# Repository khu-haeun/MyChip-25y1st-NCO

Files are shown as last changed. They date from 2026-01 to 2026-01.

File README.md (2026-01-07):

# My Chip Service 25y1st: **12-bit CORDIC-based NCO**

## Notice: What is **My Chip Service**?
An initiative in South Korea that provides MPW (Multi-Project Wafer) services using public fabrication facilities (fabs) for undergraduate and graduate students.
* **Official Website:** [https://www.moafab.kr](https://www.moafab.kr/css/myPage/bussiness/myChip/info)
* **Design Kit (Open-Source):** [ETRI 0.5um CMOS MPW Standard Cell DK](https://github.com/GoodKook/ETRI-0.5um-CMOS-MPW-Std-Cell-DK/tree/main)

---

## Project: 12-bit CORDIC-based NCO

### 1. Overview
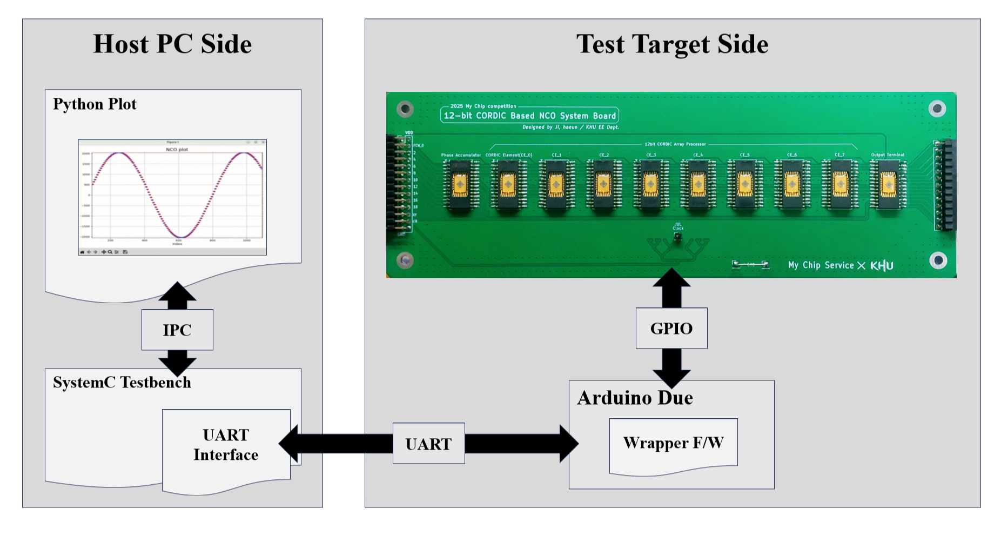
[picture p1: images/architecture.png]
Test architecture.

*Fig 1. System Architecture*

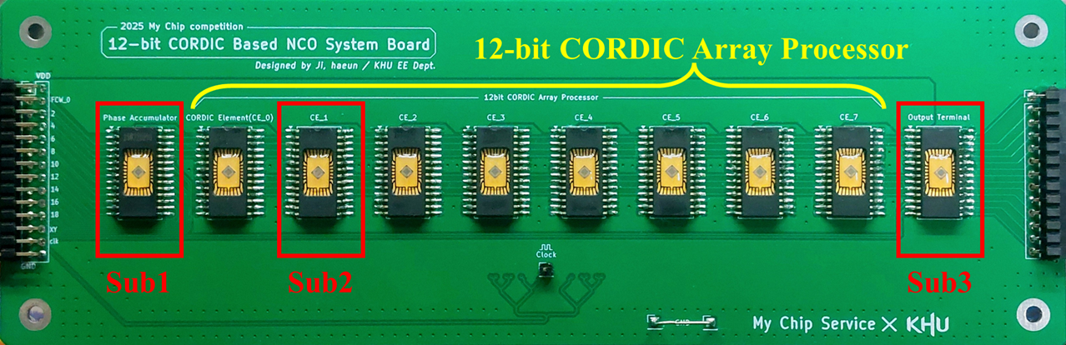
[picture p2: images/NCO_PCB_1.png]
NCO implemented on a PCB using 'My Chip'.

*Fig 2. NCO implemented on a PCB using 'My Chip'*

* **Description:** A **Numerically Controlled Oscillator (NCO)** is a digital circuit that generates synchronous, discrete-time, discrete-valued representations of sinusoidal waveforms. This project implements an NCO using a **CORDIC (Coordinate Rotation Digital Computer)** array processor to calculate trigonometric values. The complete verification environment and system structure are illustrated in **Fig 1**.

* **Key Challenges: Overcoming Physical Constraints**
    * **Core Limits:** Since the NCO design exceeded the single-chip area limit, it was **partitioned into three sub-circuits** as shown in **Fig 2**:
        1. **Phase Accumulator:** Generates the phase angle.
        2. **CORDIC Processing Element:** Performs the vector rotation.
        3. **Output Terminal:** Manages the final data output, including quadrant restoration.
    * **Pad Limits:** Each chip is limited to **28 pins**. the I/O for each sub-circuit was implemented using a **2-bit serial interface**.

---

### 2. Directory Structure
```text
├── 0_Algorithm (Algorithm development, including output plots and verification)
│   ├── c_untimed: C-based NCO algorithm
│   ├── cpp_untimed: C++ based NCO algorithm
│   └── sc_timed: SystemC-based NCO model (Clock-event-based cycle-accurate design)
|
├── 1_Parallel_IO (Reference design using parallel I/O (Not implemented in this version))
|
├── 2_Splited_IO (RTL-to-GDS with Open-Source Design Kit, including output plots and verification)
│   ├── 2_0_Top_NCO: Integrated NCO system comprising all three sub-circuits
│   ├── 2_1_Phase_Acc: Sub-circuit 1
│   ├── 2_2_Cordic_Element: Sub-circuit 2
│   ├── 2_3_Output_Terminal: Sub-circuit 3
|
└── 3_Application (application cases)
    ├── 3_0_Generate_Sinusoid: Sinusoidal waveform generation
    ├── 3_1_QPSK_Communication_prototype: QPSK simulation for the prototype board
    └── 3_2_QPSK_Communication_pcb: QPSK simulation for the final PCB

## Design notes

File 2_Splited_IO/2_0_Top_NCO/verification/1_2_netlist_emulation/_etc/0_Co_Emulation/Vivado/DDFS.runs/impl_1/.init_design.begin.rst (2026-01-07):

<?xml version="1.0"?>
<ProcessHandle Version="1" Minor="0">
    <Process Command=".planAhead." Owner="ji" Host="" Pid="7366">
    </Process>
</ProcessHandle>

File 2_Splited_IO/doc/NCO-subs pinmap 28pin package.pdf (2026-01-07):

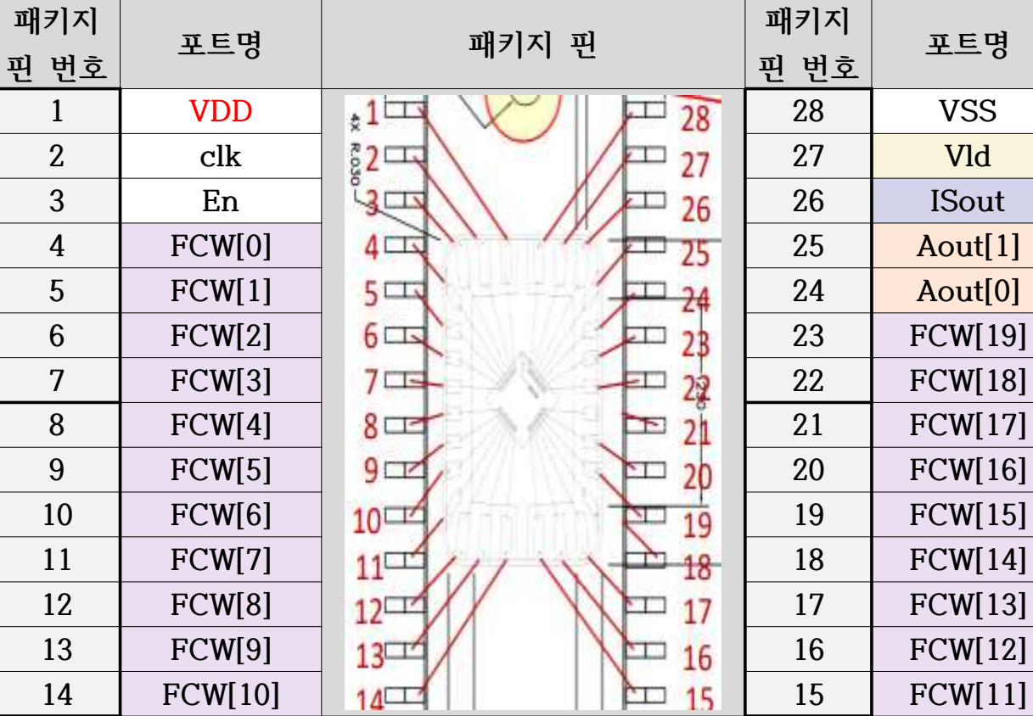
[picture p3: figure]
패키지; 포트명; 패키지 핀; 포트명 1; VDD; VSS 2; clk; Vld 3; ISout 4; FCW[0]; Aout[1] 5; FCW[1]; Aout[0] 6; FCW[2]; FCW[19] 7; FCW[3]; FCW[18] 8; FCW[4]; FCW[17] 9; FCW[5]; FCW[16]; FCW[6]; FCW[15]; FCW[7]; FCW[14]; FCW[8]; FCW[13]; FCW[9]; FCW[12]; FCW[10]; FCW[11]

< PA pin map 20+2pin>

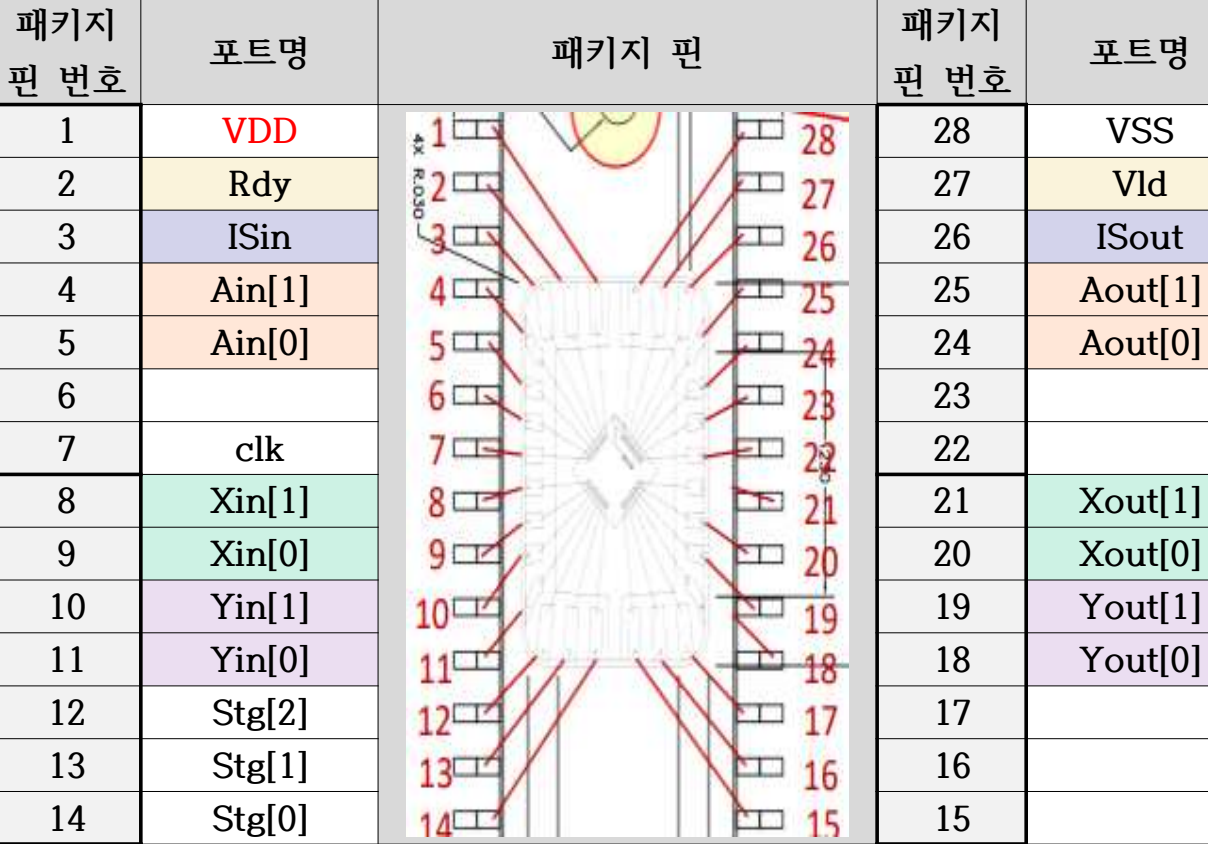
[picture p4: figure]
패키지; 포트명; 패키지 핀; 포트명 1; VDD; VSS 2; Rdy; Vld 3; ISin; ISout 4; Ain[1]; Aout[1] 5; Ain[0]; Aout[0] 6; clk; Xin[1]; Xout[1] 9; Xin[0]; Xout[0]; Yin[1]; Yout[1]; Yin[0]; Yout[0]; Stg[2]; Stg[1]; Stg[0]

< CE pin map 20+2pin>

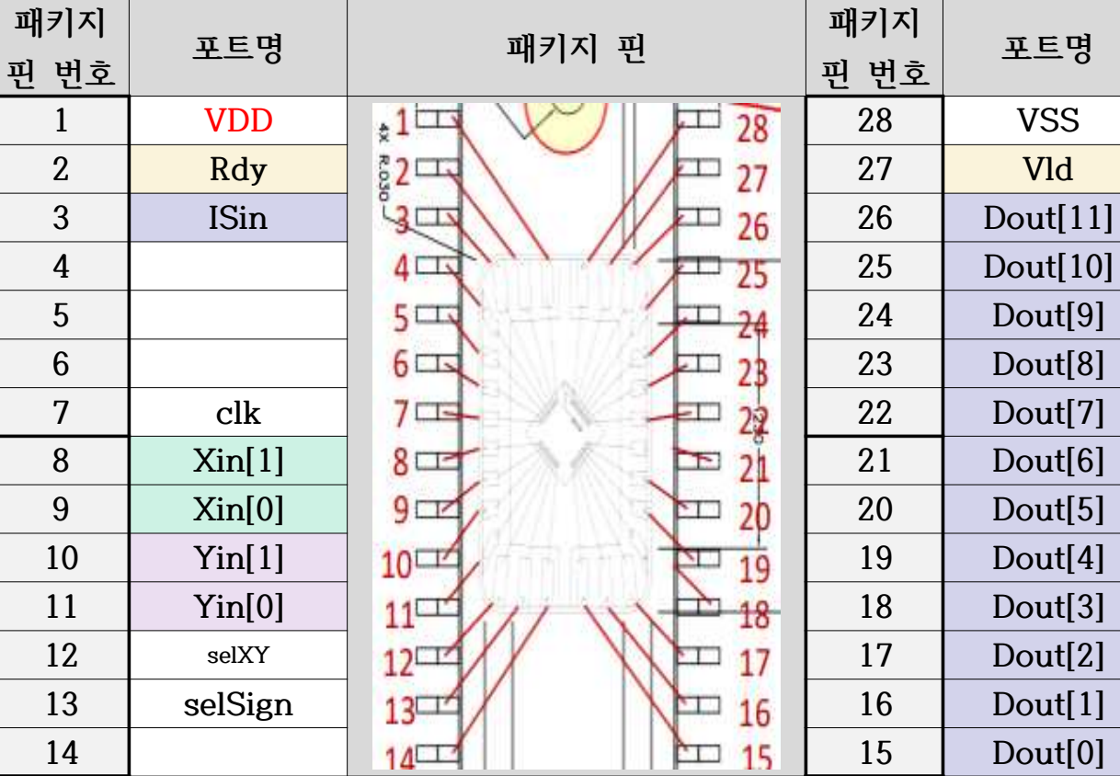
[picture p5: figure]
패키지; 포트명; 패키지 핀; 포트명 1; VDD; VSS 2; Rdy; Vld 3; ISin; Dout[11] 4; Dout[10] 5; Dout[9] 6; Dout[8] 7; clk; Dout[7] 8; Xin[1]; Dout[6] 9; Xin[0]; Dout[5]; Yin[1]; Dout[4]; Yin[0]; Dout[3]; selXY; Dout[2]; selSign; Dout[1]; Dout[0]

< CE pin map 20+2pin>

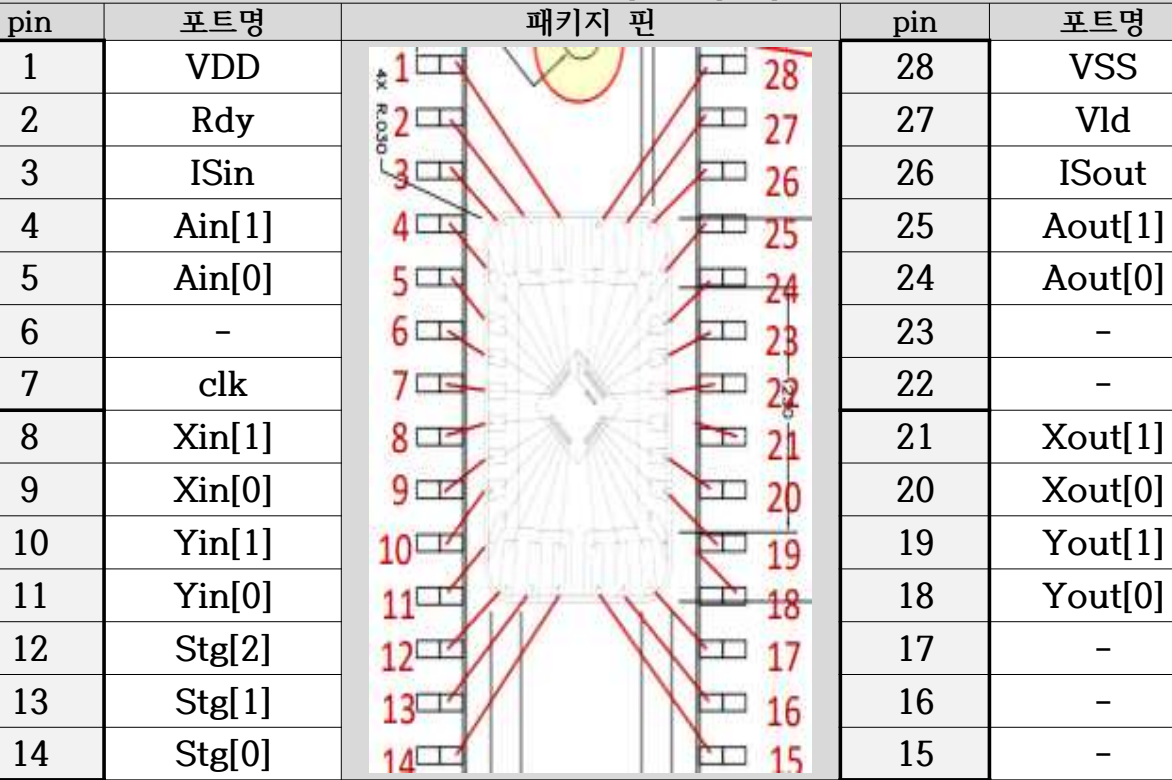
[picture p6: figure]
pin; 포트명; 패키지 핀; 포트명 1; VDD; VSS 2; Rdy; Vld 3; ISin; ISout 4; Ain[1]; Aout[1] 5; Ain[0]; Aout[0] 6; clk; Xin[1]; Xout[1] 9; Xin[0]; Xout[0]; Yin[1]; Yout[1]; Yin[0]; Yout[0]; Stg[2]; Stg[1]; Stg[0]
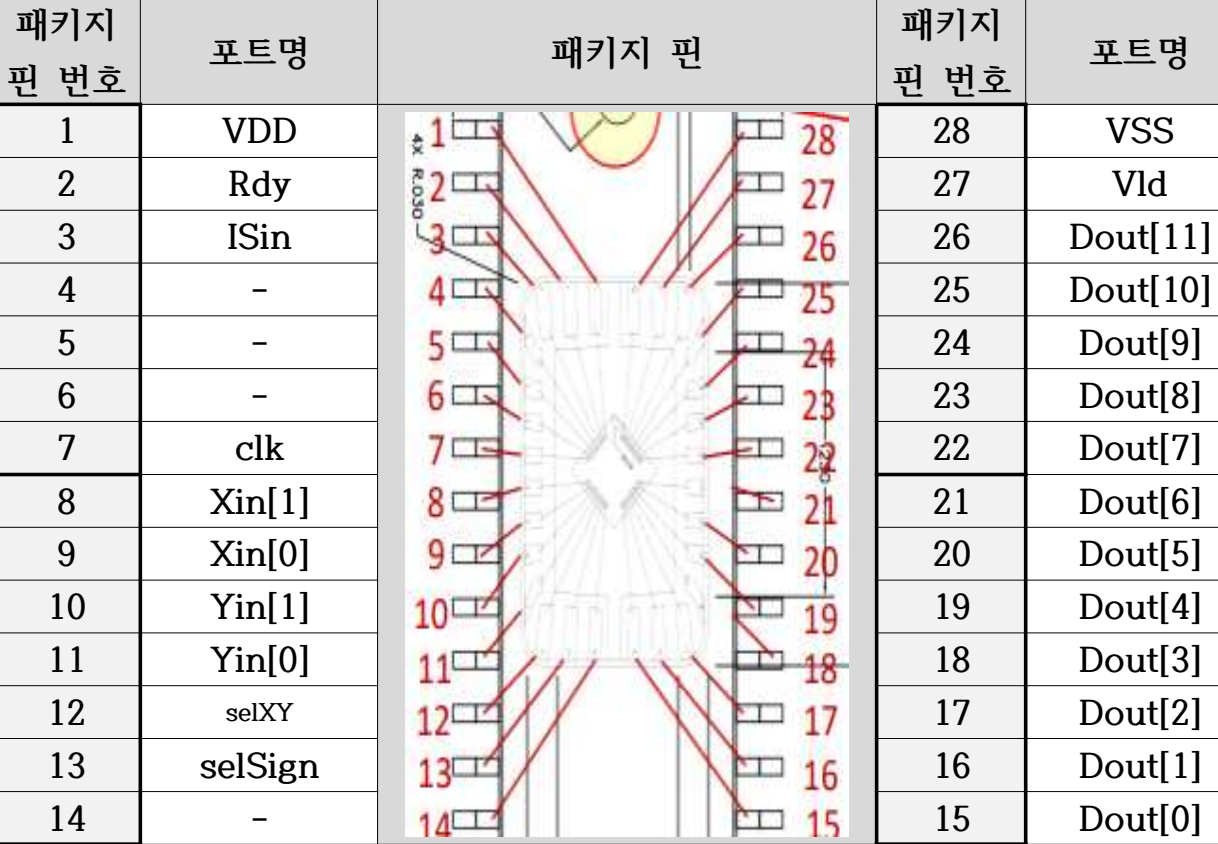
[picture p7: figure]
패키지; 포트명; 패키지 핀; 포트명 1; VDD; VSS 2; Rdy; Vld 3; ISin; Dout[11] 4; Dout[10] 5; Dout[9] 6; Dout[8] 7; clk; Dout[7] 8; Xin[1]; Dout[6] 9; Xin[0]; Dout[5]; Yin[1]; Dout[4]; Yin[0]; Dout[3]; selXY; Dout[2]; selSign; Dout[1]; Dout[0]

< NCO_sub1. Phase accumulator pin map >

< Phase Accumulator pin map 28pin>

< Output terminal pin map 24pin>

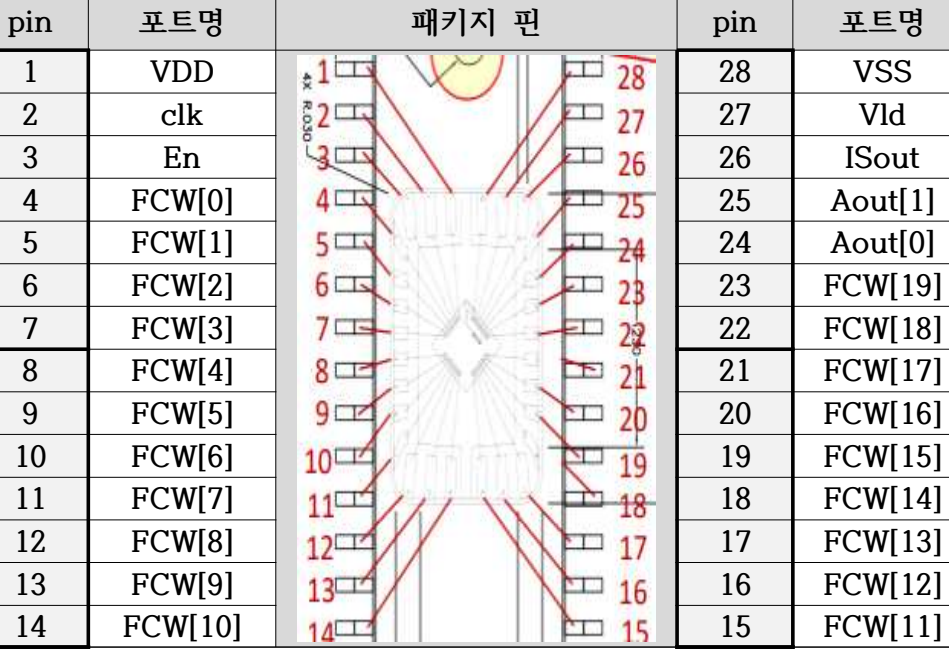
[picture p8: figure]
pin; 포트명; 패키지 핀; 포트명 1; VDD; VSS 2; clk; Vld 3; ISout 4; FCW[0]; Aout[1] 5; FCW[1]; Aout[0] 6; FCW[2]; FCW[19] 7; FCW[3]; FCW[18] 8; FCW[4]; FCW[17] 9; FCW[5]; FCW[16]; FCW[6]; FCW[15]; FCW[7]; FCW[14]; FCW[8]; FCW[13]; FCW[9]; FCW[12]; FCW[10]; FCW[11]

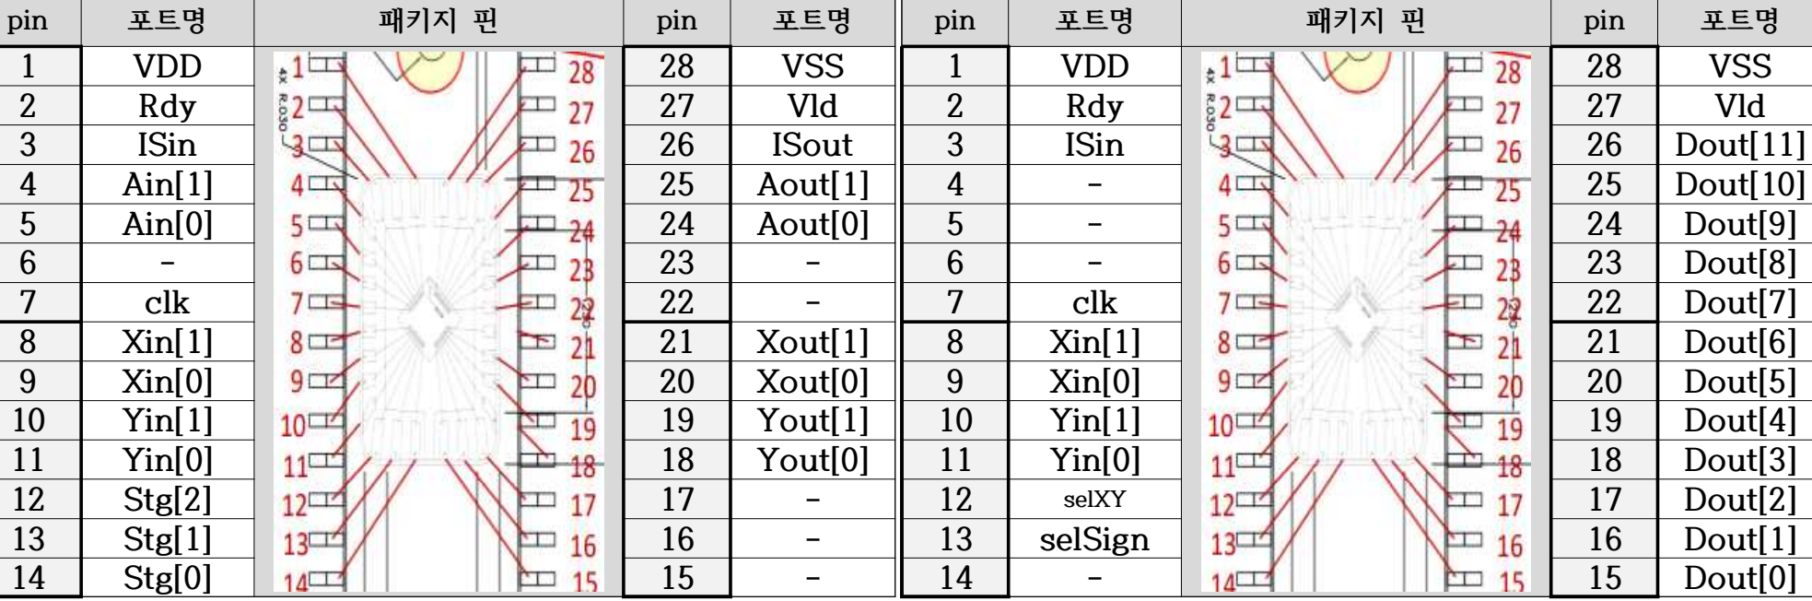
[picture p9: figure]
pin; 포트명; 패키지 핀; 포트명 1; VDD; VSS 2; Rdy; Vld 3; ISin; ISout 4; Ain[1]; Aout[1] 5; Ain[0]; Aout[0] 6; clk; Xin[1]; Xout[1] 9; Xin[0]; Xout[0]; Yin[1]; Yout[1]; Dout[4]; Yin[0]; Yout[0]; Dout[3]; Stg[2]; selXY; Dout[2]; Stg[1]; selSign; Dout[1]; Stg[0]; Dout[0]; Dout[11] 4; Dout[10] 5; Dout[9] 6; Dout[8] 7; Dout[7] 8; Dout[6] 9; Dout[5]

< NCO_sub2. CE pin map >

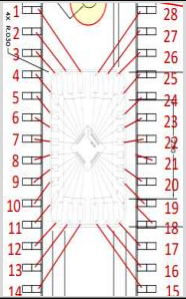
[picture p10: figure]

< NCO_sub3. Output terminal pin map >

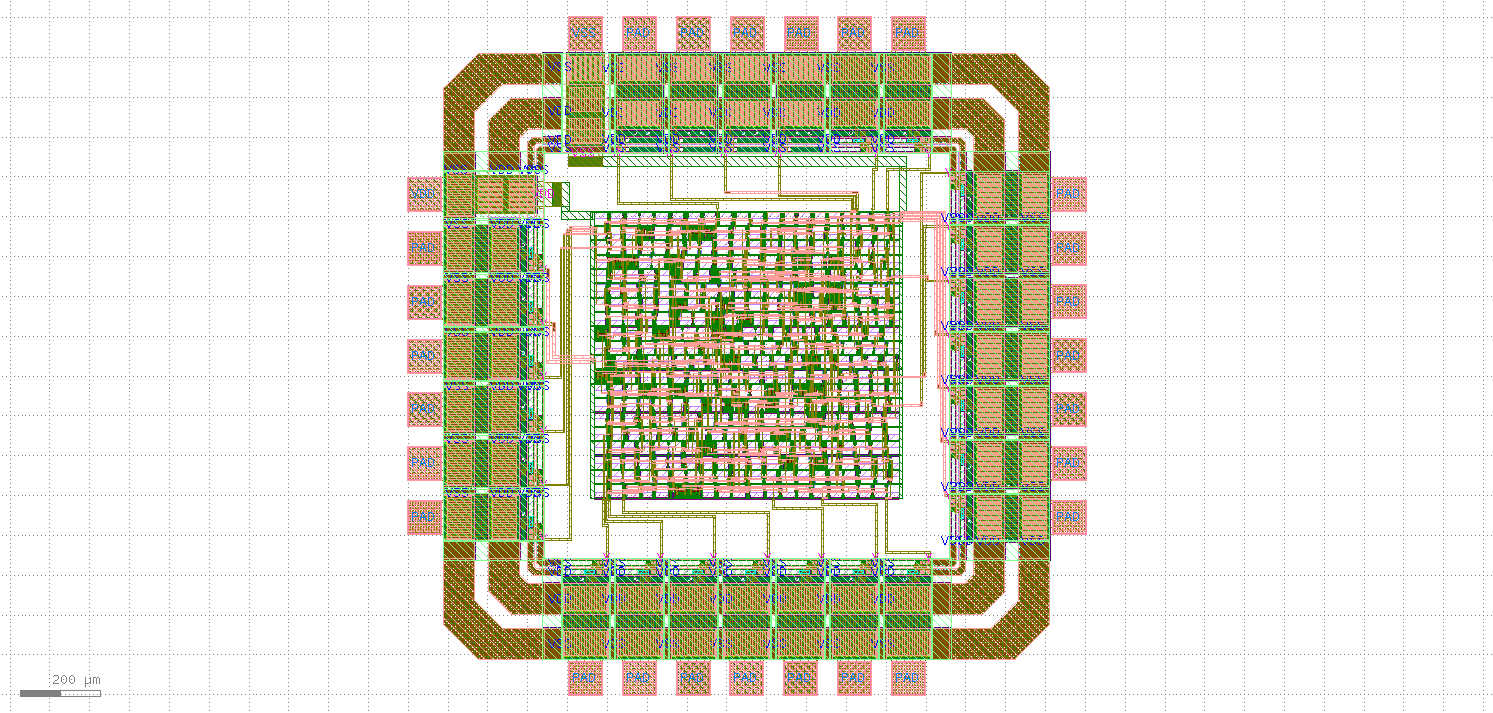
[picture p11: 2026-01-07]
2_Splited_IO/2_1_Phase_Acc/chiptop/sub1_layout.png

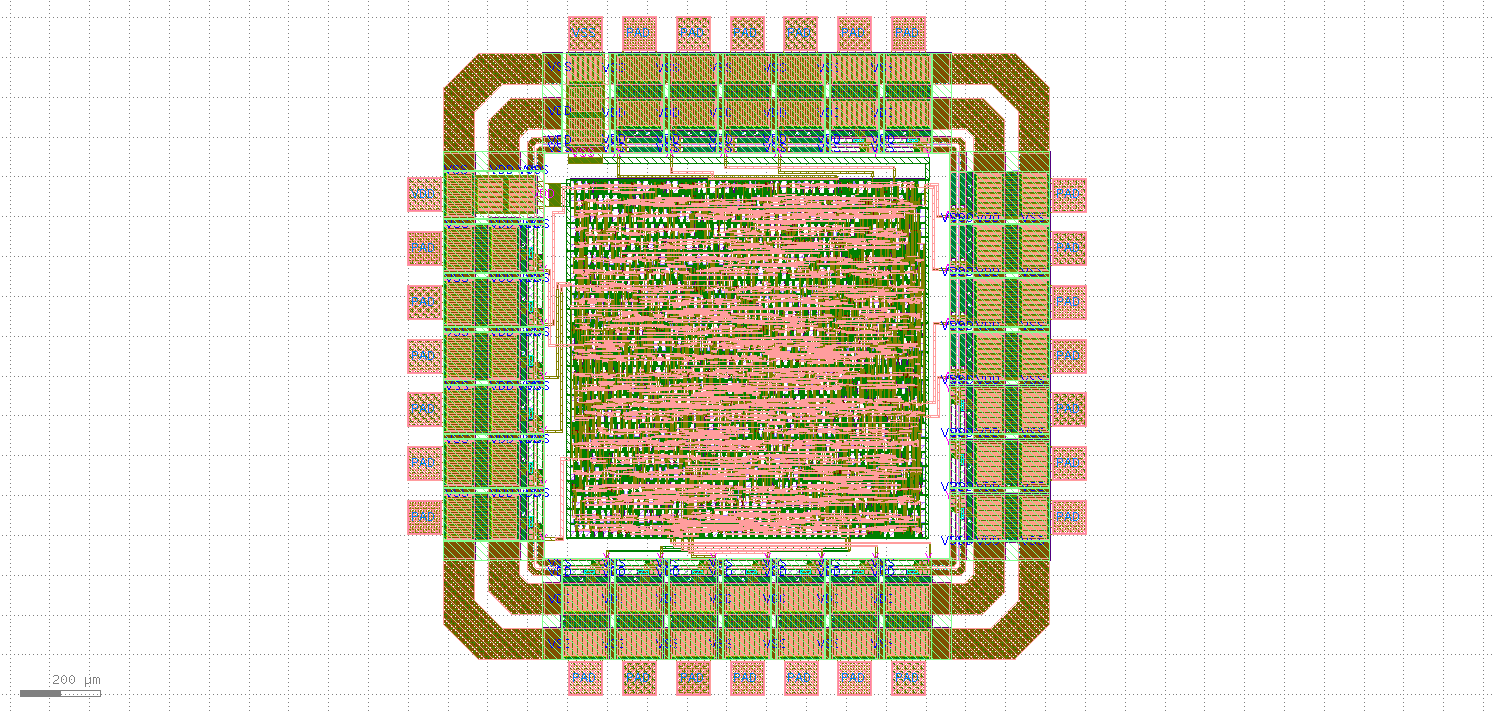
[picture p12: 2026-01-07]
2_Splited_IO/2_2_Cordic_Element/chiptop/sub2_layout.png

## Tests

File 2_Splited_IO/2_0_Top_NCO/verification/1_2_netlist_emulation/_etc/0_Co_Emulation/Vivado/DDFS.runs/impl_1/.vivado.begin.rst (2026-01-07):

<?xml version="1.0"?>
<ProcessHandle Version="1" Minor="0">
    <Process Command="vivado" Owner="ji" Host="HaEun" Pid="7321" HostCore="12" HostMemory="7781552">
    </Process>
</ProcessHandle>

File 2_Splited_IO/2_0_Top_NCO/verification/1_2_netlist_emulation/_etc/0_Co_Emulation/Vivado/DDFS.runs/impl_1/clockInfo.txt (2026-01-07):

-------------------------------------
| Tool Version : Vivado v.2024.1
| Date         : Fri Feb 28 06:55:15 2025
| Host         : HaEun
| Design       : design_1
| Device       : xc7a100t-csg324-1--
-------------------------------------

For more information on clockInfo.txt clock routing debug file see https://support.xilinx.com/s/article/000035660?language=en_US

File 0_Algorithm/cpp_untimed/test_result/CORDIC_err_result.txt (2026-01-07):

./UntimedNCO_TEST 3
[12bit CORDIC Based NCO spec.]
    phase bit        : 12 [bit]
    phase resolution : 0.09 [degree/step]

[Signed Mode]
    Avg Err: (X, Y) = (0.33%, 0.27%)
    Max Err: (X, Y) = (1.61%, 1.32%)

[Unsigned Mode]
    Avg Err: (X, Y) = (0.33%, 0.27%)
    Max Err: (X, Y) = (1.61%, 1.32%)

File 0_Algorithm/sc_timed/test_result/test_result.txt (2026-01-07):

make[1]: Entering directory '/home/haeun/ETRI-0.5um-CMOS-MPW-Std-Cell-DK/design/MyChip/2025_1st/NCO/0_Algorithm/sc_timed'
./TestBenchOfTimedNCO 1 > ./test_vec/1.txt
make[1]: Leaving directory '/home/haeun/ETRI-0.5um-CMOS-MPW-Std-Cell-DK/design/MyChip/2025_1st/NCO/0_Algorithm/sc_timed'
make[1]: Entering directory '/home/haeun/ETRI-0.5um-CMOS-MPW-Std-Cell-DK/design/MyChip/2025_1st/NCO/0_Algorithm/sc_timed'
./TestBenchOfTimedNCO 2 > ./test_vec/2.txt
make[1]: Leaving directory '/home/haeun/ETRI-0.5um-CMOS-MPW-Std-Cell-DK/design/MyChip/2025_1st/NCO/0_Algorithm/sc_timed'
make[1]: Entering directory '/home/haeun/ETRI-0.5um-CMOS-MPW-Std-Cell-DK/design/MyChip/2025_1st/NCO/0_Algorithm/sc_timed'
./TestBenchOfTimedNCO 4 > ./test_vec/4.txt
make[1]: Leaving directory '/home/haeun/ETRI-0.5um-CMOS-MPW-Std-Cell-DK/design/MyChip/2025_1st/NCO/0_Algorithm/sc_timed'
make[1]: Entering directory '/home/haeun/ETRI-0.5um-CMOS-MPW-Std-Cell-DK/design/MyChip/2025_1st/NCO/0_Algorithm/sc_timed'
./TestBenchOfTimedNCO 8 > ./test_vec/8.txt
make[1]: Leaving directory '/home/haeun/ETRI-0.5um-CMOS-MPW-Std-Cell-DK/design/MyChip/2025_1st/NCO/0_Algorithm/sc_timed'
make[1]: Entering directory '/home/haeun/ETRI-0.5um-CMOS-MPW-Std-Cell-DK/design/MyChip/2025_1st/NCO/0_Algorithm/sc_timed'
./TestBenchOfTimedNCO 16 > ./test_vec/16.txt
make[1]: Leaving directory '/home/haeun/ETRI-0.5um-CMOS-MPW-Std-Cell-DK/design/MyChip/2025_1st/NCO/0_Algorithm/sc_timed'
make[1]: Entering directory '/home/haeun/ETRI-0.5um-CMOS-MPW-Std-Cell-DK/design/MyChip/2025_1st/NCO/0_Algorithm/sc_timed'
./TestBenchOfTimedNCO 32 > ./test_vec/32.txt
make[1]: Leaving directory '/home/haeun/ETRI-0.5um-CMOS-MPW-Std-Cell-DK/design/MyChip/2025_1st/NCO/0_Algorithm/sc_timed'
make[1]: Entering directory '/home/haeun/ETRI-0.5um-CMOS-MPW-Std-Cell-DK/design/MyChip/2025_1st/NCO/0_Algorithm/sc_timed'
./TestBenchOfTimedNCO 64 > ./test_vec/64.txt
make[1]: Leaving directory '/home/haeun/ETRI-0.5um-CMOS-MPW-Std-Cell-DK/design/MyChip/2025_1st/NCO/0_Algorithm/sc_timed'
make[1]: Entering directory '/home/haeun/ETRI-0.5um-CMOS-MPW-Std-Cell-DK/design/MyChip/2025_1st/NCO/0_Algorithm/sc_timed'
./TestBenchOfTimedNCO 128 > ./test_vec/128.txt
make[1]: Leaving directory '/home/haeun/ETRI-0.5um-CMOS-MPW-Std-Cell-DK/design/MyChip/2025_1st/NCO/0_Algorithm/sc_timed'
make[1]: Entering directory '/home/haeun/ETRI-0.5um-CMOS-MPW-Std-Cell-DK/design/MyChip/2025_1st/NCO/0_Algorithm/sc_timed'
./TestBenchOfTimedNCO 256 > ./test_vec/256.txt
make[1]: Leaving directory '/home/haeun/ETRI-0.5um-CMOS-MPW-Std-Cell-DK/design/MyChip/2025_1st/NCO/0_Algorithm/sc_timed'
make[1]: Entering directory '/home/haeun/ETRI-0.5um-CMOS-MPW-Std-Cell-DK/design/MyChip/2025_1st/NCO/0_Algorithm/sc_timed'
./TestBenchOfTimedNCO 512 > ./test_vec/512.txt
make[1]: Leaving directory '/home/haeun/ETRI-0.5um-CMOS-MPW-Std-Cell-DK/design/MyChip/2025_1st/NCO/0_Algorithm/sc_timed'
make[1]: Entering directory '/home/haeun/ETRI-0.5um-CMOS-MPW-Std-Cell-DK/design/MyChip/2025_1st/NCO/0_Algorithm/sc_timed'
./TestBenchOfTimedNCO 1024 > ./test_vec/1024.txt
make[1]: Leaving directory '/home/haeun/ETRI-0.5um-CMOS-MPW-Std-Cell-DK/design/MyChip/2025_1st/NCO/0_Algorithm/sc_timed'
make[1]: Entering directory '/home/haeun/ETRI-0.5um-CMOS-MPW-Std-Cell-DK/design/MyChip/2025_1st/NCO/0_Algorithm/sc_timed'
./TestBenchOfTimedNCO 2048 > ./test_vec/2048.txt
make[1]: Leaving directory '/home/haeun/ETRI-0.5um-CMOS-MPW-Std-Cell-DK/design/MyChip/2025_1st/NCO/0_Algorithm/sc_timed'
make[1]: Entering directory '/home/haeun/ETRI-0.5um-CMOS-MPW-Std-Cell-DK/design/MyChip/2025_1st/NCO/0_Algorithm/sc_timed'
./TestBenchOfTimedNCO 4096 > ./test_vec/4096.txt
make[1]: Leaving directory '/home/haeun/ETRI-0.5um-CMOS-MPW-Std-Cell-DK/design/MyChip/2025_1st/NCO/0_Algorithm/sc_timed'
make[1]: Entering directory '/home/haeun/ETRI-0.5um-CMOS-MPW-Std-Cell-DK/design/MyChip/2025_1st/NCO/0_Algorithm/sc_timed'
./TestBenchOfTimedNCO 8192 > ./test_vec/8192.txt
make[1]: Leaving directory '/home/haeun/ETRI-0.5um-CMOS-MPW-Std-Cell-DK/design/MyChip/2025_1st/NCO/0_Algorithm/sc_timed'
make[1]: Entering directory '/home/haeun/ETRI-0.5um-CMOS-MPW-Std-Cell-DK/design/MyChip/2025_1st/NCO/0_Algorithm/sc_timed'
./TestBenchOfTimedNCO 16384 > ./test_vec/16384.txt
make[1]: Leaving directory '/home/haeun/ETRI-0.5um-CMOS-MPW-Std-Cell-DK/design/MyChip/2025_1st/NCO/0_Algorithm/sc_timed'
make[1]: Entering directory '/home/haeun/ETRI-0.5um-CMOS-MPW-Std-Cell-DK/design/MyChip/2025_1st/NCO/0_Algorithm/sc_timed'
./TestBenchOfTimedNCO 32768 > ./test_vec/32768.txt
make[1]: Leaving directory '/home/haeun/ETRI-0.5um-CMOS-MPW-Std-Cell-DK/design/MyChip/2025_1st/NCO/0_Algorithm/sc_timed'
make[1]: Entering directory '/home/haeun/ETRI-0.5um-CMOS-MPW-Std-Cell-DK/design/MyChip/2025_1st/NCO/0_Algorithm/sc_timed'
./TestBenchOfTimedNCO 65536 > ./test_vec/65536.txt
make[1]: Leaving directory '/home/haeun/ETRI-0.5um-CMOS-MPW-Std-Cell-DK/design/MyChip/2025_1st/NCO/0_Algorithm/sc_timed'
make[1]: Entering directory '/home/haeun/ETRI-0.5um-CMOS-MPW-Std-Cell-DK/design/MyChip/2025_1st/NCO/0_Algorithm/sc_timed'
./TestBenchOfTimedNCO 131072 > ./test_vec/131072.txt
make[1]: Leaving directory '/home/haeun/ETRI-0.5um-CMOS-MPW-Std-Cell-DK/design/MyChip/2025_1st/NCO/0_Algorithm/sc_timed'
make[1]: Entering directory '/home/haeun/ETRI-0.5um-CMOS-MPW-Std-Cell-DK/design/MyChip/2025_1st/NCO/0_Algorithm/sc_timed'
./TestBenchOfTimedNCO 262144 > ./test_vec/262144.txt
make[1]: Leaving directory '/home/haeun/ETRI-0.5um-CMOS-MPW-Std-Cell-DK/design/MyChip/2025_1st/NCO/0_Algorithm/sc_timed'
make[1]: Entering directory '/home/haeun/ETRI-0.5um-CMOS-MPW-Std-Cell-DK/design/MyChip/2025_1st/NCO/0_Algorithm/sc_timed'
./TestBenchOfTimedNCO 524288 > ./test_vec/524288.txt
make[1]: Leaving directory '/home/haeun/ETRI-0.5um-CMOS-MPW-Std-Cell-DK/design/MyChip/2025_1st/NCO/0_Algorithm/sc_timed'
FCW=1: Pass
FCW=2: Pass
FCW=4: Pass
FCW=8: Pass
FCW=16: Pass
FCW=32: Pass
FCW=64: Pass
FCW=128: Pass
FCW=256: Pass
FCW=512: Pass
FCW=1024: Pass
FCW=2048: Pass
FCW=4096: Pass
FCW=8192: Pass
FCW=16384: Pass
FCW=32768: Pass
FCW=65536: Pass
FCW=131072: Pass
FCW=262144: Pass
FCW=524288: Pass
All PASS :)

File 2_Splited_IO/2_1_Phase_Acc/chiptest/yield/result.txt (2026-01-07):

chip 0 result: PASS / err=0
chip 0 result: PASS / err=0
chip 0 result: PASS / err=0
chip 100 result: PASS / err=0
chip 100 result: PASS / err=0
chip 100 result: PASS / err=0
chip 100 result: PASS / err=0
chip 100 result: PASS / err=0
chip 100 result: PASS / err=0
chip 100 result: PASS / err=0

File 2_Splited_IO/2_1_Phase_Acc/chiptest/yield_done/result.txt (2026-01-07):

chip: phase_accumulator
5v
chip 0 result: PASS / err=0
chip 1 result: PASS / err=0
chip 2 result: PASS / err=0
chip 3 result: FAIL / err=1982
chip 4 result: FAIL / err=1917
chip 5 result: FAIL / err=652
chip 6 result: FAIL / err=934
chip 7 result: PASS / err=0
chip 8 result: FAIL / err=21
chip 9 result: PASS / err=0
chip 10 result: FAIL / err=1830
chip 11 result: PASS / err=0
chip 12 result: FAIL / err=651
chip 13 result: FAIL / err=1830
chip 14 result: PASS / err=0
chip 15 result: PASS / err=0
chip 16 result: PASS / err=0
chip 17 result: FAIL / err=821
chip 18 result: PASS / err=0
chip 19 result: PASS / err=0
3.3v
chip 0 result: PASS / err=0
chip 1 result: PASS / err=0
chip 2 result: PASS / err=0
chip 3 result: FAIL / err=2055
chip 4 result: FAIL / err=1917
chip 5 result: FAIL / err=652
chip 6 result: FAIL / err=934
chip 7 result: PASS / err=0
chip 8 result: FAIL / err=21
chip 9 result: PASS / err=0
chip 10 result: FAIL / err=1917
chip 11 result: PASS / err=0
chip 12 result: FAIL / err=651
chip 13 result: FAIL / err=821
chip 14 result: PASS / err=0
chip 15 result: PASS / err=0
chip 16 result: PASS / err=0
chip 17 result: FAIL / err=821
chip 18 result: PASS / err=0
chip 19 result: PASS / err=0

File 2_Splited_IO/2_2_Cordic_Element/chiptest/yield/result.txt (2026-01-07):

chip 6 result: PASS / err=0
chip 0 result: FAIL / err=784
chip 0 result: PASS / err=0
chip 0 result: PASS / err=0
chip 0 result: PASS / err=0
chip 0 result: PASS / err=0
chip 0 result: PASS / err=0
chip 0 result: PASS / err=0
chip 0 result: PASS / err=0
chip 0 result: FAIL / err=1987
chip 0 result: PASS / err=0
chip 0 result: PASS / err=0
chip 100 result: PASS / err=0
chip 100 result: PASS / err=0
chip 100 result: PASS / err=0
chip 100 result: FAIL / err=1975
chip 100 result: FAIL / err=107
chip 100 result: FAIL / err=1984
chip 100 result: PASS / err=0

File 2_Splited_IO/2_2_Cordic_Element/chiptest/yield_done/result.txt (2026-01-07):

chip: cordic element
5v
chip 0 result: PASS / err=0
chip 1 result: PASS / err=0
chip 2 result: PASS / err=0
chip 3 result: PASS / err=0
chip 4 result: PASS / err=0
chip 5 result: PASS / err=0
chip 6 result: PASS / err=0
chip 7 result: PASS / err=0
chip 8 result: FAIL / err=2057
chip 9 result: PASS / err=0
chip 10 result: PASS / err=0
chip 11 result: PASS / err=0
chip 12 result: PASS / err=0
chip 13 result: PASS / err=0
chip 14 result: PASS / err=0
chip 15 result: PASS / err=0
chip 16 result: FAIL / err=361
chip 17 result: PASS / err=0
chip 18 result: PASS / err=0
chip 19 result: PASS / err=0
3.3v
chip 0 result: PASS / err=0
chip 1 result: PASS / err=0
chip 2 result: PASS / err=0
chip 3 result: PASS / err=0
chip 4 result: PASS / err=0
chip 5 result: PASS / err=0
chip 6 result: PASS / err=0
chip 7 result: PASS / err=0
chip 8 result: FAIL / err=2237
chip 9 result: PASS / err=0
chip 10 result: PASS / err=0
chip 11 result: PASS / err=0
chip 12 result: PASS / err=0
chip 13 result: PASS / err=0
chip 14 result: PASS / err=0
chip 15 result: PASS / err=0
chip 16 result: FAIL / err=362
chip 17 result: PASS / err=0
chip 18 result: PASS / err=0
chip 19 result: PASS / err=0

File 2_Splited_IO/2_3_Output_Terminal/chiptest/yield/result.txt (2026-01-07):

chip 0 result: PASS / err=0
chip 0 result: PASS / err=0
chip 100 result: PASS / err=0
chip 100 result: PASS / err=0
chip 100 result: PASS / err=0
chip 100 result: PASS / err=0
chip 101 result: PASS / err=0
chip 40 result: PASS / err=0
chip 40 result: PASS / err=0
chip 101 result: PASS / err=0
chip 123 result: PASS / err=0
chip 100 result: PASS / err=0
chip 100 result: PASS / err=0
chip 100 result: FAIL / err=25
chip 100 result: FAIL / err=50
chip 100 result: PASS / err=0
chip 100 result: PASS / err=0

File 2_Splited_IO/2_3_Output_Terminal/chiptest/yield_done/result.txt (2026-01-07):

chip: output terminal
5v
chip 0 result: PASS / err=0
chip 1 result: PASS / err=0
chip 2 result: FAIL / err=779
chip 3 result: FAIL / err=2000
chip 4 result: FAIL / err=2000
chip 5 result: PASS / err=0
chip 6 result: PASS / err=0
chip 7 result: FAIL / err=2000
chip 8 result: FAIL / err=1713
chip 9 result: FAIL / err=2000
chip 10 result: FAIL / err=1996
chip 11 result: PASS / err=0
chip 12 result: FAIL / err=1996
chip 13 result: FAIL / err=2000
chip 14 result: FAIL / err=1997
chip 15 result: FAIL / err=765
chip 16 result: PASS / err=0
chip 17 result: PASS / err=0
chip 18 result: PASS / err=0
chip 19 result: PASS / err=0
3.3v
chip 0 result: PASS / err=0
chip 1 result: PASS / err=0
chip 2 result: FAIL / err=846
chip 3 result: FAIL / err=2000
chip 4 result: FAIL / err=2000
chip 5 result: PASS / err=0
chip 6 result: PASS / err=0
chip 7 result: FAIL / err=2000
chip 8 result: FAIL / err=1713
chip 9 result: FAIL / err=1713
chip 10 result: FAIL / err=1713
chip 11 result: PASS / err=0
chip 12 result: FAIL / err=1713
chip 13 result: FAIL / err=1713
chip 14 result: FAIL / err=1713
chip 15 result: FAIL / err=789
chip 16 result: PASS / err=0
chip 17 result: PASS / err=0
chip 18 result: PASS / err=0
chip 19 result: PASS / err=0

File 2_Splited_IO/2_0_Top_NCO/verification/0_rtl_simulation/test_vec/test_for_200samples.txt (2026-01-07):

[MODE:0][Sel:Y][FCW:       1][      61]Ref =    -16 vs DUT =    -16 ==> PASS
[MODE:0][Sel:Y][FCW:       1][      68]Ref =    -16 vs DUT =    -16 ==> PASS
[MODE:0][Sel:Y][FCW:       1][      75]Ref =    -16 vs DUT =    -16 ==> PASS
[MODE:0][Sel:Y][FCW:       1][      82]Ref =    -16 vs DUT =    -16 ==> PASS
[MODE:0][Sel:Y][FCW:       1][      89]Ref =    -16 vs DUT =    -16 ==> PASS
[MODE:0][Sel:Y][FCW:       1][      96]Ref =    -16 vs DUT =    -16 ==> PASS
[MODE:0][Sel:Y][FCW:       1][     103]Ref =    -16 vs DUT =    -16 ==> PASS
[MODE:0][Sel:Y][FCW:       1][     110]Ref =    -16 vs DUT =    -16 ==> PASS
[MODE:0][Sel:Y][FCW:       1][     117]Ref =    -16 vs DUT =    -16 ==> PASS
[MODE:0][Sel:Y][FCW:       1][     124]Ref =    -16 vs DUT =    -16 ==> PASS
[MODE:0][Sel:Y][FCW:       1][     131]Ref =    -16 vs DUT =    -16 ==> PASS
[MODE:0][Sel:Y][FCW:       1][     138]Ref =    -16 vs DUT =    -16 ==> PASS
[MODE:0][Sel:Y][FCW:       1][     145]Ref =    -16 vs DUT =    -16 ==> PASS
[MODE:0][Sel:Y][FCW:       1][     152]Ref =    -16 vs DUT =    -16 ==> PASS
[MODE:0][Sel:Y][FCW:       1][     159]Ref =    -16 vs DUT =    -16 ==> PASS
[MODE:0][Sel:Y][FCW:       1][     166]Ref =    -16 vs DUT =    -16 ==> PASS
[MODE:0][Sel:Y][FCW:       1][     173]Ref =    -16 vs DUT =    -16 ==> PASS
[MODE:0][Sel:Y][FCW:       1][     180]Ref =    -16 vs DUT =    -16 ==> PASS
[MODE:0][Sel:Y][FCW:       1][     187]Ref =    -16 vs DUT =    -16 ==> PASS
[MODE:0][Sel:Y][FCW:       1][     194]Ref =    -16 vs DUT =    -16 ==> PASS
[MODE:0][Sel:Y][FCW:       2][      61]Ref =    -16 vs DUT =    -16 ==> PASS
[MODE:0][Sel:Y][FCW:       2][      68]Ref =    -16 vs DUT =    -16 ==> PASS
[MODE:0][Sel:Y][FCW:       2][      75]Ref =    -16 vs DUT =    -16 ==> PASS
[MODE:0][Sel:Y][FCW:       2][      82]Ref =    -16 vs DUT =    -16 ==> PASS
[MODE:0][Sel:Y][FCW:       2][      89]Ref =    -16 vs DUT =    -16 ==> PASS
[MODE:0][Sel:Y][FCW:       2][      96]Ref =    -16 vs DUT =    -16 ==> PASS
[MODE:0][Sel:Y][FCW:       2][     103]Ref =    -16 vs DUT =    -16 ==> PASS
[MODE:0][Sel:Y][FCW:       2][     110]Ref =    -16 vs DUT =    -16 ==> PASS
[MODE:0][Sel:Y][FCW:       2][     117]Ref =    -16 vs DUT =    -16 ==> PASS
[MODE:0][Sel:Y][FCW:       2][     124]Ref =    -16 vs DUT =    -16 ==> PASS
[MODE:0][Sel:Y][FCW:       2][     131]Ref =    -16 vs DUT =    -16 ==> PASS
[MODE:0][Sel:Y][FCW:       2][     138]Ref =    -16 vs DUT =    -16 ==> PASS
[MODE:0][Sel:Y][FCW:       2][     145]Ref =    -16 vs DUT =    -16 ==> PASS
[MODE:0][Sel:Y][FCW:       2][     152]Ref =    -16 vs DUT =    -16 ==> PASS
[MODE:0][Sel:Y][FCW:       2][     159]Ref =    -16 vs DUT =    -16 ==> PASS
[MODE:0][Sel:Y][FCW:       2][     166]Ref =    -16 vs DUT =    -16 ==> PASS
[MODE:0][Sel:Y][FCW:       2][     173]Ref =    -16 vs DUT =    -16 ==> PASS
[MODE:0][Sel:Y][FCW:       2][     180]Ref =    -16 vs DUT =    -16 ==> PASS
[MODE:0][Sel:Y][FCW:       2][     187]Ref =    -16 vs DUT =    -16 ==> PASS
[MODE:0][Sel:Y][FCW:       2][     194]Ref =    -16 vs DUT =    -16 ==> PASS
[MODE:0][Sel:Y][FCW:       4][      61]Ref =    -16 vs DUT =    -16 ==> PASS
[MODE:0][Sel:Y][FCW:       4][      68]Ref =    -16 vs DUT =    -16 ==> PASS
[MODE:0][Sel:Y][FCW:       4][      75]Ref =    -16 vs DUT =    -16 ==> PASS
[MODE:0][Sel:Y][FCW:       4][      82]Ref =    -16 vs DUT =    -16 ==> PASS
[MODE:0][Sel:Y][FCW:       4][      89]Ref =    -16 vs DUT =    -16 ==> PASS
[MODE:0][Sel:Y][FCW:       4][      96]Ref =    -16 vs DUT =    -16 ==> PASS
[MODE:0][Sel:Y][FCW:       4][     103]Ref =    -16 vs DUT =    -16 ==> PASS
[MODE:0][Sel:Y][FCW:       4][     110]Ref =    -16 vs DUT =    -16 ==> PASS
[MODE:0][Sel:Y][FCW:       4][     117]Ref =    -16 vs DUT =    -16 ==> PASS
[MODE:0][Sel:Y][FCW:       4][     124]Ref =    -16 vs DUT =    -16 ==> PASS
[MODE:0][Sel:Y][FCW:       4][     131]Ref =    -16 vs DUT =    -16 ==> PASS
[MODE:0][Sel:Y][FCW:       4][     138]Ref =    -16 vs DUT =    -16 ==> PASS
[MODE:0][Sel:Y][FCW:       4][     145]Ref =    -16 vs DUT =    -16 ==> PASS
[MODE:0][Sel:Y][FCW:       4][     152]Ref =    -16 vs DUT =    -16 ==> PASS
[MODE:0][Sel:Y][FCW:       4][     159]Ref =    -16 vs DUT =    -16 ==> PASS
[MODE:0][Sel:Y][FCW:       4][     166]Ref =    -16 vs DUT =    -16 ==> PASS
[MODE:0][Sel:Y][FCW:       4][     173]Ref =    -16 vs DUT =    -16 ==> PASS
[MODE:0][Sel:Y][FCW:       4][     180]Ref =    -16 vs DUT =    -16 ==> PASS
[MODE:0][Sel:Y][FCW:       4][     187]Ref =    -16 vs DUT =    -16 ==> PASS
[MODE:0][Sel:Y][FCW:       4][     194]Ref =    -16 vs DUT =    -16 ==> PASS
[MODE:0][Sel:Y][FCW:       8][      61]Ref =    -16 vs DUT =    -16 ==> PASS
[MODE:0][Sel:Y][FCW:       8][      68]Ref =    -16 vs DUT =    -16 ==> PASS
[MODE:0][Sel:Y][FCW:       8][      75]Ref =    -16 vs DUT =    -16 ==> PASS
[MODE:0][Sel:Y][FCW:       8][      82]Ref =    -16 vs DUT =    -16 ==> PASS
[MODE:0][Sel:Y][FCW:       8][      89]Ref =    -16 vs DUT =    -16 ==> PASS
[MODE:0][Sel:Y][FCW:       8][      96]Ref =    -16 vs DUT =    -16 ==> PASS
[MODE:0][Sel:Y][FCW:       8][     103]Ref =    -16 vs DUT =    -16 ==> PASS
[MODE:0][Sel:Y][FCW:       8][     110]Ref =    -16 vs DUT =    -16 ==> PASS
[MODE:0][Sel:Y][FCW:       8][     117]Ref =    -16 vs DUT =    -16 ==> PASS
[MODE:0][Sel:Y][FCW:       8][     124]Ref =    -16 vs DUT =    -16 ==> PASS
[MODE:0][Sel:Y][FCW:       8][     131]Ref =    -16 vs DUT =    -16 ==> PASS
[MODE:0][Sel:Y][FCW:       8][     138]Ref =    -16 vs DUT =    -16 ==> PASS
[MODE:0][Sel:Y][FCW:       8][     145]Ref =    -16 vs DUT =    -16 ==> PASS
[MODE:0][Sel:Y][FCW:       8][     152]Ref =    -16 vs DUT =    -16 ==> PASS
[MODE:0][Sel:Y][FCW:       8][     159]Ref =    -16 vs DUT =    -16 ==> PASS
[MODE:0][Sel:Y][FCW:       8][     166]Ref =    -16 vs DUT =    -16 ==> PASS
[MODE:0][Sel:Y][FCW:       8][     173]Ref =    -16 vs DUT =    -16 ==> PASS
[MODE:0][Sel:Y][FCW:       8][     180]Ref =    -16 vs DUT =    -16 ==> PASS
[MODE:0][Sel:Y][FCW:       8][     187]Ref =    -16 vs DUT =    -16 ==> PASS
[MODE:0][Sel:Y][FCW:       8][     194]Ref =    -16 vs DUT =    -16 ==> PASS
[MODE:0][Sel:Y][FCW:      16][      61]Ref =    -16 vs DUT =    -16 ==> PASS
[MODE:0][Sel:Y][FCW:      16][      68]Ref =    -16 vs DUT =    -16 ==> PASS
[MODE:0][Sel:Y][FCW:      16][      75]Ref =    -16 vs DUT =    -16 ==> PASS
[MODE:0][Sel:Y][FCW:      16][      82]Ref =    -16 vs DUT =    -16 ==> PASS
[MODE:0][Sel:Y][FCW:      16][      89]Ref =    -16 vs DUT =    -16 ==> PASS
[MODE:0][Sel:Y][FCW:      16][      96]Ref =    -16 vs DUT =    -16 ==> PASS
[MODE:0][Sel:Y][FCW:      16][     103]Ref =    -16 vs DUT =    -16 ==> PASS
[MODE:0][Sel:Y][FCW:      16][     110]Ref =    -16 vs DUT =    -16 ==> PASS
[MODE:0][Sel:Y][FCW:      16][     117]Ref =    -16 vs DUT =    -16 ==> PASS
[MODE:0][Sel:Y][FCW:      16][     124]Ref =    -16 vs DUT =    -16 ==> PASS
[MODE:0][Sel:Y][FCW:      16][     131]Ref =    -16 vs DUT =    -16 ==> PASS
[MODE:0][Sel:Y][FCW:      16][     138]Ref =    -16 vs DUT =    -16 ==> PASS
[MODE:0][Sel:Y][FCW:      16][     145]Ref =    -16 vs DUT =    -16 ==> PASS
[MODE:0][Sel:Y][FCW:      16][     152]Ref =    -16 vs DUT =    -16 ==> PASS
[MODE:0][Sel:Y][FCW:      16][     159]Ref =    -16 vs DUT =    -16 ==> PASS
[MODE:0][Sel:Y][FCW:      16][     166]Ref =     14 vs DUT =     14 ==> PASS
[MODE:0][Sel:Y][FCW:      16][     173]Ref =     14 vs DUT =     14 ==> PASS
[MODE:0][Sel:Y][FCW:      16][     180]Ref =     14 vs DUT =     14 ==> PASS
[MODE:0][Sel:Y][FCW:      16][     187]Ref =     14 vs DUT =     14 ==> PASS
[MODE:0][Sel:Y][FCW:      16][     194]Ref =     14 vs DUT =     14 ==> PASS
[MODE:0][Sel:Y][FCW:      32][      61]Ref =    -16 vs DUT =    -16 ==> PASS
[MODE:0][Sel:Y][FCW:      32][      68]Ref =    -16 vs DUT =    -16 ==> PASS
[MODE:0][Sel:Y][FCW:      32][      75]Ref =    -16 vs DUT =    -16 ==> PASS
[MODE:0][Sel:Y][FCW:      32][      82]Ref =    -16 vs DUT =    -16 ==> PASS
[MODE:0][Sel:Y][FCW:      32][      89]Ref =    -16 vs DUT =    -16 ==> PASS
[MODE:0][Sel:Y][FCW:      32][      96]Ref =    -16 vs DUT =    -16 ==> PASS
[MODE:0][Sel:Y][FCW:      32][     103]Ref =    -16 vs DUT =    -16 ==> PASS
[MODE:0][Sel:Y][FCW:      32][     110]Ref =     14 vs DUT =     14 ==> PASS
[MODE:0][Sel:Y][FCW:      32][     117]Ref =     14 vs DUT =     14 ==> PASS
[MODE:0][Sel:Y][FCW:      32][     124]Ref =     14 vs DUT =     14 ==> PASS
[MODE:0][Sel:Y][FCW:      32][     131]Ref =     14 vs DUT =     14 ==> PASS
[MODE:0][Sel:Y][FCW:      32][     138]Ref =     14 vs DUT =     14 ==> PASS
[MODE:0][Sel:Y][FCW:      32][     145]Ref =     14 vs DUT =     14 ==> PASS
[MODE:0][Sel:Y][FCW:      32][     152]Ref =     14 vs DUT =     14 ==> PASS
[MODE:0][Sel:Y][FCW:      32][     159]Ref =     14 vs DUT =     14 ==> PASS
[MODE:0][Sel:Y][FCW:      32][     166]Ref =     14 vs DUT =     14 ==> PASS
[MODE:0][Sel:Y][FCW:      32][     173]Ref =     14 vs DUT =     14 ==> PASS
[MODE:0][Sel:Y][FCW:      32][     180]Ref =     14 vs DUT =     14 ==> PASS
[MODE:0][Sel:Y][FCW:      32][     187]Ref =     14 vs DUT =     14 ==> PASS
[MODE:0][Sel:Y][FCW:      32][     194]Ref =     14 vs DUT =     14 ==> PASS
[MODE:0][Sel:Y][FCW:      64][      61]Ref =    -16 vs DUT =    -16 ==> PASS
[MODE:0][Sel:Y][FCW:      64][      68]Ref =    -16 vs DUT =    -16 ==> PASS
[MODE:0][Sel:Y][FCW:      64][      75]Ref =    -16 vs DUT =    -16 ==> PASS
[MODE:0][Sel:Y][FCW:      64][      82]Ref =     14 vs DUT =     14 ==> PASS
[MODE:0][Sel:Y][FCW:      64][      89]Ref =     14 vs DUT =     14 ==> PASS
[MODE:0][Sel:Y][FCW:      64][      96]Ref =     14 vs DUT =     14 ==> PASS
[MODE:0][Sel:Y][FCW:      64][     103]Ref =     14 vs DUT =     14 ==> PASS
[MODE:0][Sel:Y][FCW:      64][     110]Ref =     14 vs DUT =     14 ==> PASS
[MODE:0][Sel:Y][FCW:      64][     117]Ref =     14 vs DUT =     14 ==> PASS
[MODE:0][Sel:Y][FCW:      64][     124]Ref =     14 vs DUT =     14 ==> PASS
[MODE:0][Sel:Y][FCW:      64][     131]Ref =     14 vs DUT =     14 ==> PASS
[MODE:0][Sel:Y][FCW:      64][     138]Ref =     14 vs DUT =     14 ==> PASS
[MODE:0][Sel:Y][FCW:      64][     145]Ref =     14 vs DUT =     14 ==> PASS
[MODE:0][Sel:Y][FCW:      64][     152]Ref =     14 vs DUT =     14 ==> PASS
[MODE:0][Sel:Y][FCW:      64][     159]Ref =     14 vs DUT =     14 ==> PASS
[MODE:0][Sel:Y][FCW:      64][     166]Ref =     14 vs DUT =     14 ==> PASS
[MODE:0][Sel:Y][FCW:      64][     173]Ref =     14 vs DUT =     14 ==> PASS
[MODE:0][Sel:Y][FCW:      64][     180]Ref =     14 vs DUT =     14 ==> PASS
[MODE:0][Sel:Y][FCW:      64][     187]Ref =     14 vs DUT =     14 ==> PASS
[MODE:0][Sel:Y][FCW:      64][     194]Ref =     14 vs DUT =     14 ==> PASS
[MODE:0][Sel:Y][FCW:     128][      61]Ref =    -16 vs DUT =    -16 ==> PASS
[MODE:0][Sel:Y][FCW:     128][      68]Ref =     14 vs DUT =     14 ==> PASS
[MODE:0][Sel:Y][FCW:     128][      75]Ref =     14 vs DUT =     14 ==> PASS
[MODE:0][Sel:Y][FCW:     128][      82]Ref =     14 vs DUT =     14 ==> PASS
[MODE:0][Sel:Y][FCW:     128][      89]Ref =     14 vs DUT =     14 ==> PASS
[MODE:0][Sel:Y][FCW:     128][      96]Ref =     14 vs DUT =     14 ==> PASS
[MODE:0][Sel:Y][FCW:     128][     103]Ref =     14 vs DUT =     14 ==> PASS
[MODE:0][Sel:Y][FCW:     128][     110]Ref =     14 vs DUT =     14 ==> PASS
[MODE:0][Sel:Y][FCW:     128][     117]Ref =     14 vs DUT =     14 ==> PASS
[MODE:0][Sel:Y][FCW:     128][     124]Ref =     14 vs DUT =     14 ==> PASS
[MODE:0][Sel:Y][FCW:     128][     131]Ref =     14 vs DUT =     14 ==> PASS
[MODE:0][Sel:Y][FCW:     128][     138]Ref =     14 vs DUT =     14 ==> PASS
[MODE:0][Sel:Y][FCW:     128][     145]Ref =     14 vs DUT =     14 ==> PASS
[MODE:0][Sel:Y][FCW:     128][     152]Ref =     14 vs DUT =     14 ==> PASS
[MODE:0][Sel:Y][FCW:     128][     159]Ref =     14 vs DUT =     14 ==> PASS
[MODE:0][Sel:Y][FCW:     128][     166]Ref =     14 vs DUT =     14 ==> PASS
[MODE:0][Sel:Y][FCW:     128][     173]Ref =     14 vs DUT =     14 ==> PASS
[MODE:0][Sel:Y][FCW:     128][     180]Ref =     14 vs DUT =     14 ==> PASS
[MODE:0][Sel:Y][FCW:     128][     187]Ref =     14 vs DUT =     14 ==> PASS
[MODE:0][Sel:Y][FCW:     128][     194]Ref =     14 vs DUT =     14 ==> PASS
[MODE:0][Sel:Y][FCW:     256][      61]Ref =     14 vs DUT =     14 ==> PASS
[MODE:0][Sel:Y][FCW:     256][      68]Ref =     14 vs DUT =     14 ==> PASS
[MODE:0][Sel:Y][FCW:     256][      75]Ref =     14 vs DUT =     14 ==> PASS
[MODE:0][Sel:Y][FCW:     256][      82]Ref =     14 vs DUT =     14 ==> PASS
[MODE:0][Sel:Y][FCW:     256][      89]Ref =     14 vs DUT =     14 ==> PASS
[MODE:0][Sel:Y][FCW:     256][      96]Ref =     14 vs DUT =     14 ==> PASS
[MODE:0][Sel:Y][FCW:     256][     103]Ref =     14 vs DUT =     14 ==> PASS
[MODE:0][Sel:Y][FCW:     256][     110]Ref =     14 vs DUT =     14 ==> PASS
[MODE:0][Sel:Y][FCW:     256][     117]Ref =     14 vs DUT =     14 ==> PASS
[MODE:0][Sel:Y][FCW:     256][     124]Ref =     14 vs DUT =     14 ==> PASS
[MODE:0][Sel:Y][FCW:     256][     131]Ref =     48 vs DUT =     48 ==> PASS
[MODE:0][Sel:Y][FCW:     256][     138]Ref =     48 vs DUT =     48 ==> PASS
[MODE:0][Sel:Y][FCW:     256][     145]Ref =     48 vs DUT =     48 ==> PASS
[MODE:0][Sel:Y][FCW:     256][     152]Ref =     48 vs DUT =     48 ==> PASS
[MODE:0][Sel:Y][FCW:     256][     159]Ref =     48 vs DUT =     48 ==> PASS
[MODE:0][Sel:Y][FCW:     256][     166]Ref =     48 vs DUT =     48 ==> PASS
[MODE:0][Sel:Y][FCW:     256][     173]Ref =     48 vs DUT =     48 ==> PASS
[MODE:0][Sel:Y][FCW:     256][     180]Ref =     48 vs DUT =     48 ==> PASS
[MODE:0][Sel:Y][FCW:     256][     187]Ref =     48 vs DUT =     48 ==> PASS
[MODE:0][Sel:Y][FCW:     256][     194]Ref =     48 vs DUT =     48 ==> PASS
[MODE:0][Sel:Y][FCW:     512][      61]Ref =     14 vs DUT =     14 ==> PASS
[MODE:0][Sel:Y][FCW:     512][      68]Ref =     14 vs DUT =     14 ==> PASS
[MODE:0][Sel:Y][FCW:     512][      75]Ref =     14 vs DUT =     14 ==> PASS
[MODE:0][Sel:Y][FCW:     512][      82]Ref =     14 vs DUT =     14 ==> PASS
[MODE:0][Sel:Y][FCW:     512][      89]Ref =     14 vs DUT =     14 ==> PASS
[MODE:0][Sel:Y][FCW:     512][      96]Ref =     48 vs DUT =     48 ==> PASS
[MODE:0][Sel:Y][FCW:     512][     103]Ref =     48 vs DUT =     48 ==> PASS
[MODE:0][Sel:Y][FCW:     512][     110]Ref =     48 vs DUT =     48 ==> PASS
[MODE:0][Sel:Y][FCW:     512][     117]Ref =     48 vs DUT =     48 ==> PASS
[MODE:0][Sel:Y][FCW:     512][     124]Ref =     48 vs DUT =     48 ==> PASS
[MODE:0][Sel:Y][FCW:     512][     131]Ref =     78 vs DUT =     78 ==> PASS
[MODE:0][Sel:Y][FCW:     512][     138]Ref =     78 vs DUT =     78 ==> PASS
[MODE:0][Sel:Y][FCW:     512][     145]Ref =     78 vs DUT =     78 ==> PASS
[MODE:0][Sel:Y][FCW:     512][     152]Ref =     78 vs DUT =     78 ==> PASS
[MODE:0][Sel:Y][FCW:     512][     159]Ref =    110 vs DUT =    110 ==> PASS
[MODE:0][Sel:Y][FCW:     512][     166]Ref =    110 vs DUT =    110 ==> PASS
[MODE:0][Sel:Y][FCW:     512][     173]Ref =    110 vs DUT =    110 ==> PASS
[MODE:0][Sel:Y][FCW:     512][     180]Ref =    110 vs DUT =    110 ==> PASS
[MODE:0][Sel:Y][FCW:     512][     187]Ref =    110 vs DUT =    110 ==> PASS
[MODE:0][Sel:Y][FCW:     512][     194]Ref =    140 vs DUT =    140 ==> PASS
[MODE:0][Sel:Y][FCW:    1024][      61]Ref =     14 vs DUT =     14 ==> PASS
[MODE:0][Sel:Y][FCW:    1024][      68]Ref =     14 vs DUT =     14 ==> PASS
[MODE:0][Sel:Y][FCW:    1024][      75]Ref =     48 vs DUT =     48 ==> PASS
[MODE:0][Sel:Y][FCW:    1024][      82]Ref =     48 vs DUT =     48 ==> PASS
[MODE:0][Sel:Y][FCW:    1024][      89]Ref =     48 vs DUT =     48 ==> PASS
[MODE:0][Sel:Y][FCW:    1024][      96]Ref =     78 vs DUT =     78 ==> PASS
[MODE:0][Sel:Y][FCW:    1024][     103]Ref =     78 vs DUT =     78 ==> PASS
[MODE:0][Sel:Y][FCW:    1024][     110]Ref =    110 vs DUT =    110 ==> PASS
[MODE:0][Sel:Y][FCW:    1024][     117]Ref =    110 vs DUT =    110 ==> PASS
[MODE:0][Sel:Y][FCW:    1024][     124]Ref =    140 vs DUT =    140 ==> PASS
[MODE:0][Sel:Y][FCW:    1024][     131]Ref =    140 vs DUT =    140 ==> PASS
[MODE:0][Sel:Y][FCW:    1024][     138]Ref =    140 vs DUT =    140 ==> PASS
[MODE:0][Sel:Y][FCW:    1024][     145]Ref =    175 vs DUT =    175 ==> PASS
[MODE:0][Sel:Y][FCW:    1024][     152]Ref =    175 vs DUT =    175 ==> PASS
[MODE:0][Sel:Y][FCW:    1024][     159]Ref =    175 vs DUT =    175 ==> PASS
[MODE:0][Sel:Y][FCW:    1024][     166]Ref =    205 vs DUT =    205 ==> PASS
[MODE:0][Sel:Y][FCW:    1024][     173]Ref =    205 vs DUT =    205 ==> PASS
[MODE:0][Sel:Y][FCW:    1024][     180]Ref =    237 vs DUT =    237 ==> PASS
[MODE:0][Sel:Y][FCW:    1024][     187]Ref =    237 vs DUT =    237 ==> PASS
[MODE:0][Sel:Y][FCW:    1024][     194]Ref =    237 vs DUT =    237 ==> PASS
[MODE:0][Sel:Y][FCW:    2048][      61]Ref =     14 vs DUT =     14 ==> PASS
[MODE:0][Sel:Y][FCW:    2048][      68]Ref =     48 vs DUT =     48 ==> PASS
[MODE:0][Sel:Y][FCW:    2048][      75]Ref =     78 vs DUT =     78 ==> PASS
[MODE:0][Sel:Y][FCW:    2048][      82]Ref =    110 vs DUT =    110 ==> PASS
[MODE:0][Sel:Y][FCW:    2048][      89]Ref =    140 vs DUT =    140 ==> PASS
[MODE:0][Sel:Y][FCW:    2048][      96]Ref =    140 vs DUT =    140 ==> PASS
[MODE:0][Sel:Y][FCW:    2048][     103]Ref =    175 vs DUT =    175 ==> PASS
[MODE:0][Sel:Y][FCW:    2048][     110]Ref =    205 vs DUT =    205 ==> PASS
[MODE:0][Sel:Y][FCW:    2048][     117]Ref =    237 vs DUT =    237 ==> PASS
[MODE:0][Sel:Y][FCW:    2048][     124]Ref =    237 vs DUT =    237 ==> PASS
[MODE:0][Sel:Y][FCW:    2048][     131]Ref =    267 vs DUT =    267 ==> PASS
[MODE:0][Sel:Y][FCW:    2048][     138]Ref =    301 vs DUT =    301 ==> PASS
[MODE:0][Sel:Y][FCW:    2048][     145]Ref =    331 vs DUT =    331 ==> PASS
[MODE:0][Sel:Y][FCW:    2048][     152]Ref =    363 vs DUT =    363 ==> PASS
[MODE:0][Sel:Y][FCW:    2048][     159]Ref =    393 vs DUT =    393 ==> PASS
[MODE:0][Sel:Y][FCW:    2048][     166]Ref =    393 vs DUT =    393 ==> PASS
[MODE:0][Sel:Y][FCW:    2048][     173]Ref =    425 vs DUT =    425 ==> PASS
[MODE:0][Sel:Y][FCW:    2048][     180]Ref =    455 vs DUT =    455 ==> PASS
[MODE:0][Sel:Y][FCW:    2048][     187]Ref =    487 vs DUT =    487 ==> PASS
[MODE:0][Sel:Y][FCW:    2048][     194]Ref =    487 vs DUT =    487 ==> PASS
[MODE:0][Sel:Y][FCW:    4096][      61]Ref =     48 vs DUT =     48 ==> PASS
[MODE:0][Sel:Y][FCW:    4096][      68]Ref =    110 vs DUT =    110 ==> PASS
[MODE:0][Sel:Y][FCW:    4096][      75]Ref =    140 vs DUT =    140 ==> PASS
[MODE:0][Sel:Y][FCW:    4096][      82]Ref =    205 vs DUT =    205 ==> PASS
[MODE:0][Sel:Y][FCW:    4096][      89]Ref =    237 vs DUT =    237 ==> PASS
[MODE:0][Sel:Y][FCW:    4096][      96]Ref =    301 vs DUT =    301 ==> PASS
[MODE:0][Sel:Y][FCW:    4096][     103]Ref =    363 vs DUT =    363 ==> PASS
[MODE:0][Sel:Y][FCW:    4096][     110]Ref =    393 vs DUT =    393 ==> PASS
[MODE:0][Sel:Y][FCW:    4096][     117]Ref =    455 vs DUT =    455 ==> PASS
[MODE:0][Sel:Y][FCW:    4096][     124]Ref =    487 vs DUT =    487 ==> PASS
[MODE:0][Sel:Y][FCW:    4096][     131]Ref =    548 vs DUT =    548 ==> PASS
[MODE:0][Sel:Y][FCW:    4096][     138]Ref =    608 vs DUT =    608 ==> PASS
[MODE:0][Sel:Y][FCW:    4096][     145]Ref =    638 vs DUT =    638 ==> PASS
[MODE:0][Sel:Y][FCW:    4096][     152]Ref =    684 vs DUT =    684 ==> PASS
[MODE:0][Sel:Y][FCW:    4096][     159]Ref =    743 vs DUT =    743 ==> PASS
[MODE:0][Sel:Y][FCW:    4096][     166]Ref =    774 vs DUT =    774 ==> PASS
[MODE:0][Sel:Y][FCW:    4096][     173]Ref =    832 vs DUT =    832 ==> PASS
[MODE:0][Sel:Y][FCW:    4096][     180]Ref =    860 vs DUT =    860 ==> PASS
[MODE:0][Sel:Y][FCW:    4096][     187]Ref =    919 vs DUT =    919 ==> PASS
[MODE:0][Sel:Y][FCW:    4096][     194]Ref =    975 vs DUT =    975 ==> PASS
[MODE:0][Sel:Y][FCW:    8192][      61]Ref =    110 vs DUT =    110 ==> PASS
[MODE:0][Sel:Y][FCW:    8192][      68]Ref =    205 vs DUT =    205 ==> PASS
[MODE:0][Sel:Y][FCW:    8192][      75]Ref =    301 vs DUT =    301 ==> PASS
[MODE:0][Sel:Y][FCW:    8192][      82]Ref =    393 vs DUT =    393 ==> PASS
[MODE:0][Sel:Y][FCW:    8192][      89]Ref =    487 vs DUT =    487 ==> PASS
[MODE:0][Sel:Y][FCW:    8192][      96]Ref =    608 vs DUT =    608 ==> PASS
[MODE:0][Sel:Y][FCW:    8192][     103]Ref =    684 vs DUT =    684 ==> PASS
[MODE:0][Sel:Y][FCW:    8192][     110]Ref =    774 vs DUT =    774 ==> PASS
[MODE:0][Sel:Y][FCW:    8192][     117]Ref =    860 vs DUT =    860 ==> PASS
[MODE:0][Sel:Y][FCW:    8192][     124]Ref =    975 vs DUT =    975 ==> PASS
[MODE:0][Sel:Y][FCW:    8192][     131]Ref =   1057 vs DUT =   1057 ==> PASS
[MODE:0][Sel:Y][FCW:    8192][     138]Ref =   1137 vs DUT =   1137 ==> PASS
[MODE:0][Sel:Y][FCW:    8192][     145]Ref =   1215 vs DUT =   1215 ==> PASS
[MODE:0][Sel:Y][FCW:    8192][     152]Ref =   1289 vs DUT =   1289 ==> PASS
[MODE:0][Sel:Y][FCW:    8192][     159]Ref =   1385 vs DUT =   1385 ==> PASS
[MODE:0][Sel:Y][FCW:    8192][     166]Ref =   1438 vs DUT =   1438 ==> PASS
[MODE:0][Sel:Y][FCW:    8192][     173]Ref =   1524 vs DUT =   1524 ==> PASS
[MODE:0][Sel:Y][FCW:    8192][     180]Ref =   1589 vs DUT =   1589 ==> PASS
[MODE:0][Sel:Y][FCW:    8192][     187]Ref =   1645 vs DUT =   1645 ==> PASS
[MODE:0][Sel:Y][FCW:    8192][     194]Ref =   1700 vs DUT =   1700 ==> PASS
[MODE:0][Sel:Y][FCW:   16384][      61]Ref =    205 vs DUT =    205 ==> PASS
[MODE:0][Sel:Y][FCW:   16384][      68]Ref =    393 vs DUT =    393 ==> PASS
[MODE:0][Sel:Y][FCW:   16384][      75]Ref =    608 vs DUT =    608 ==> PASS
[MODE:0][Sel:Y][FCW:   16384][      82]Ref =    774 vs DUT =    774 ==> PASS
[MODE:0][Sel:Y][FCW:   16384][      89]Ref =    975 vs DUT =    975 ==> PASS
[MODE:0][Sel:Y][FCW:   16384][      96]Ref =   1137 vs DUT =   1137 ==> PASS
[MODE:0][Sel:Y][FCW:   16384][     103]Ref =   1289 vs DUT =   1289 ==> PASS
[MODE:0][Sel:Y][FCW:   16384][     110]Ref =   1438 vs DUT =   1438 ==> PASS
[MODE:0][Sel:Y][FCW:   16384][     117]Ref =   1589 vs DUT =   1589 ==> PASS
[MODE:0][Sel:Y][FCW:   16384][     124]Ref =   1700 vs DUT =   1700 ==> PASS
[MODE:0][Sel:Y][FCW:   16384][     131]Ref =   1812 vs DUT =   1812 ==> PASS
[MODE:0][Sel:Y][FCW:   16384][     138]Ref =   1892 vs DUT =   1892 ==> PASS
[MODE:0][Sel:Y][FCW:   16384][     145]Ref =   1963 vs DUT =   1963 ==> PASS
[MODE:0][Sel:Y][FCW:   16384][     152]Ref =   2009 vs DUT =   2009 ==> PASS
[MODE:0][Sel:Y][FCW:   16384][     159]Ref =   2036 vs DUT =   2036 ==> PASS
[MODE:0][Sel:Y][FCW:   16384][     166]Ref =   2044 vs DUT =   2044 ==> PASS
[MODE:0][Sel:Y][FCW:   16384][     173]Ref =   2036 vs DUT =   2036 ==> PASS
[MODE:0][Sel:Y][FCW:   16384][     180]Ref =   2009 vs DUT =   2009 ==> PASS
[MODE:0][Sel:Y][FCW:   16384][     187]Ref =   1953 vs DUT =   1953 ==> PASS
[MODE:0][Sel:Y][FCW:   16384][     194]Ref =   1892 vs DUT =   1892 ==> PASS
[MODE:0][Sel:Y][FCW:   32768][      61]Ref =    393 vs DUT =    393 ==> PASS
[MODE:0][Sel:Y][FCW:   32768][      68]Ref =    774 vs DUT =    774 ==> PASS
[MODE:0][Sel:Y][FCW:   32768][      75]Ref =   1137 vs DUT =   1137 ==> PASS
[MODE:0][Sel:Y][FCW:   32768][      82]Ref =   1438 vs DUT =   1438 ==> PASS
[MODE:0][Sel:Y][FCW:   32768][      89]Ref =   1700 vs DUT =   1700 ==> PASS
[MODE:0][Sel:Y][FCW:   32768][      96]Ref =   1892 vs DUT =   1892 ==> PASS
[MODE:0][Sel:Y][FCW:   32768][     103]Ref =   2009 vs DUT =   2009 ==> PASS
[MODE:0][Sel:Y][FCW:   32768][     110]Ref =   2044 vs DUT =   2044 ==> PASS
[MODE:0][Sel:Y][FCW:   32768][     117]Ref =   2009 vs DUT =   2009 ==> PASS
[MODE:0][Sel:Y][FCW:   32768][     124]Ref =   1892 vs DUT =   1892 ==> PASS
[MODE:0][Sel:Y][FCW:   32768][     131]Ref =   1700 vs DUT =   1700 ==> PASS
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

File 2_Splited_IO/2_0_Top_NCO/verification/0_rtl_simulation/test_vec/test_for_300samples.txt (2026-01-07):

[MODE:0][Sel:Y][FCW:       1][      61]Ref =    -16 vs DUT =    -16 ==> PASS
[MODE:0][Sel:Y][FCW:       1][      68]Ref =    -16 vs DUT =    -16 ==> PASS
[MODE:0][Sel:Y][FCW:       1][      75]Ref =    -16 vs DUT =    -16 ==> PASS
[MODE:0][Sel:Y][FCW:       1][      82]Ref =    -16 vs DUT =    -16 ==> PASS
[MODE:0][Sel:Y][FCW:       1][      89]Ref =    -16 vs DUT =    -16 ==> PASS
[MODE:0][Sel:Y][FCW:       1][      96]Ref =    -16 vs DUT =    -16 ==> PASS
[MODE:0][Sel:Y][FCW:       1][     103]Ref =    -16 vs DUT =    -16 ==> PASS
[MODE:0][Sel:Y][FCW:       1][     110]Ref =    -16 vs DUT =    -16 ==> PASS
[MODE:0][Sel:Y][FCW:       1][     117]Ref =    -16 vs DUT =    -16 ==> PASS
[MODE:0][Sel:Y][FCW:       1][     124]Ref =    -16 vs DUT =    -16 ==> PASS
[MODE:0][Sel:Y][FCW:       1][     131]Ref =    -16 vs DUT =    -16 ==> PASS
[MODE:0][Sel:Y][FCW:       1][     138]Ref =    -16 vs DUT =    -16 ==> PASS
[MODE:0][Sel:Y][FCW:       1][     145]Ref =    -16 vs DUT =    -16 ==> PASS
[MODE:0][Sel:Y][FCW:       1][     152]Ref =    -16 vs DUT =    -16 ==> PASS
[MODE:0][Sel:Y][FCW:       1][     159]Ref =    -16 vs DUT =    -16 ==> PASS
[MODE:0][Sel:Y][FCW:       1][     166]Ref =    -16 vs DUT =    -16 ==> PASS
[MODE:0][Sel:Y][FCW:       1][     173]Ref =    -16 vs DUT =    -16 ==> PASS
[MODE:0][Sel:Y][FCW:       1][     180]Ref =    -16 vs DUT =    -16 ==> PASS
[MODE:0][Sel:Y][FCW:       1][     187]Ref =    -16 vs DUT =    -16 ==> PASS
[MODE:0][Sel:Y][FCW:       1][     194]Ref =    -16 vs DUT =    -16 ==> PASS
[MODE:0][Sel:Y][FCW:       1][     201]Ref =    -16 vs DUT =    -16 ==> PASS
[MODE:0][Sel:Y][FCW:       1][     208]Ref =    -16 vs DUT =    -16 ==> PASS
[MODE:0][Sel:Y][FCW:       1][     215]Ref =    -16 vs DUT =    -16 ==> PASS
[MODE:0][Sel:Y][FCW:       1][     222]Ref =    -16 vs DUT =    -16 ==> PASS
[MODE:0][Sel:Y][FCW:       1][     229]Ref =    -16 vs DUT =    -16 ==> PASS
[MODE:0][Sel:Y][FCW:       1][     236]Ref =    -16 vs DUT =    -16 ==> PASS
[MODE:0][Sel:Y][FCW:       1][     243]Ref =    -16 vs DUT =    -16 ==> PASS
[MODE:0][Sel:Y][FCW:       1][     250]Ref =    -16 vs DUT =    -16 ==> PASS
[MODE:0][Sel:Y][FCW:       1][     257]Ref =    -16 vs DUT =    -16 ==> PASS
[MODE:0][Sel:Y][FCW:       1][     264]Ref =    -16 vs DUT =    -16 ==> PASS
[MODE:0][Sel:Y][FCW:       1][     271]Ref =    -16 vs DUT =    -16 ==> PASS
[MODE:0][Sel:Y][FCW:       1][     278]Ref =    -16 vs DUT =    -16 ==> PASS
[MODE:0][Sel:Y][FCW:       1][     285]Ref =    -16 vs DUT =    -16 ==> PASS
[MODE:0][Sel:Y][FCW:       1][     292]Ref =    -16 vs DUT =    -16 ==> PASS
[MODE:0][Sel:Y][FCW:       1][     299]Ref =    -16 vs DUT =    -16 ==> PASS
[MODE:0][Sel:Y][FCW:       2][      61]Ref =    -16 vs DUT =    -16 ==> PASS
[MODE:0][Sel:Y][FCW:       2][      68]Ref =    -16 vs DUT =    -16 ==> PASS
[MODE:0][Sel:Y][FCW:       2][      75]Ref =    -16 vs DUT =    -16 ==> PASS
[MODE:0][Sel:Y][FCW:       2][      82]Ref =    -16 vs DUT =    -16 ==> PASS
[MODE:0][Sel:Y][FCW:       2][      89]Ref =    -16 vs DUT =    -16 ==> PASS
[MODE:0][Sel:Y][FCW:       2][      96]Ref =    -16 vs DUT =    -16 ==> PASS
[MODE:0][Sel:Y][FCW:       2][     103]Ref =    -16 vs DUT =    -16 ==> PASS
[MODE:0][Sel:Y][FCW:       2][     110]Ref =    -16 vs DUT =    -16 ==> PASS
[MODE:0][Sel:Y][FCW:       2][     117]Ref =    -16 vs DUT =    -16 ==> PASS
[MODE:0][Sel:Y][FCW:       2][     124]Ref =    -16 vs DUT =    -16 ==> PASS
[MODE:0][Sel:Y][FCW:       2][     131]Ref =    -16 vs DUT =    -16 ==> PASS
[MODE:0][Sel:Y][FCW:       2][     138]Ref =    -16 vs DUT =    -16 ==> PASS
[MODE:0][Sel:Y][FCW:       2][     145]Ref =    -16 vs DUT =    -16 ==> PASS
[MODE:0][Sel:Y][FCW:       2][     152]Ref =    -16 vs DUT =    -16 ==> PASS
[MODE:0][Sel:Y][FCW:       2][     159]Ref =    -16 vs DUT =    -16 ==> PASS
[MODE:0][Sel:Y][FCW:       2][     166]Ref =    -16 vs DUT =    -16 ==> PASS
[MODE:0][Sel:Y][FCW:       2][     173]Ref =    -16 vs DUT =    -16 ==> PASS
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

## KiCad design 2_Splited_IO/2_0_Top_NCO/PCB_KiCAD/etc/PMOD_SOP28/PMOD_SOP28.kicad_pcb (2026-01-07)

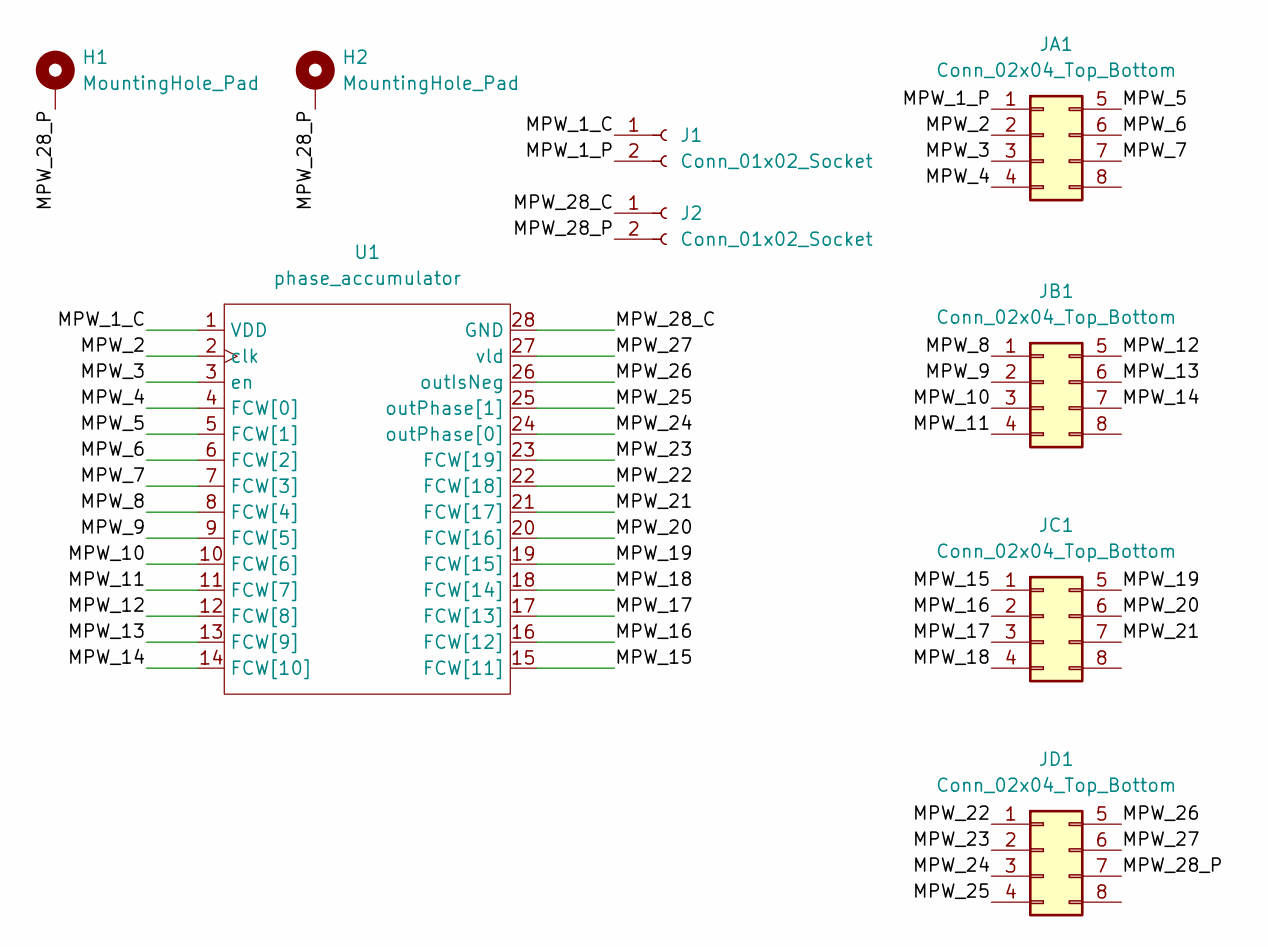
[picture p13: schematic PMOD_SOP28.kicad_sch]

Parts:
H1, H2: MountingHole_Pad; MountingHole_3.2mm_M3_Pad
J1, J2: Conn_01x02_Socket; PinHeader_1x02_P2.54mm_Vertical
JA1: Conn_02x04_Top_Bottom; PinSocket_2x04_P2.54mm_Vertical
JB1: Conn_02x04_Top_Bottom; PinSocket_2x04_P2.54mm_Vertical
JC1: Conn_02x04_Top_Bottom; PinSocket_2x04_P2.54mm_Vertical
JD1: Conn_02x04_Top_Bottom; PinSocket_2x04_P2.54mm_Vertical
U1: phase_accumulator; user_socket28_2p54

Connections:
/MPW_1_C: J1.1, U1.1 (VDD)
/MPW_1_P: J1.2, JA1.1
/MPW_2: JA1.2, U1.2 (clk)
/MPW_3: JA1.3, U1.3 (en)
/MPW_4: JA1.4, U1.4 (FCW[0])
/MPW_5: JA1.5, U1.5 (FCW[1])
/MPW_6: JA1.6, U1.6 (FCW[2])
/MPW_7: JA1.7, U1.7 (FCW[3])
/MPW_8: JB1.1, U1.8 (FCW[4])
/MPW_9: JB1.2, U1.9 (FCW[5])
/MPW_10: JB1.3, U1.10 (FCW[6])
/MPW_11: JB1.4, U1.11 (FCW[7])
/MPW_12: JB1.5, U1.12 (FCW[8])
/MPW_13: JB1.6, U1.13 (FCW[9])
/MPW_14: JB1.7, U1.14 (FCW[10])
/MPW_15: JC1.1, U1.15 (FCW[11])
/MPW_16: JC1.2, U1.16 (FCW[12])
/MPW_17: JC1.3, U1.17 (FCW[13])
/MPW_18: JC1.4, U1.18 (FCW[14])
/MPW_19: JC1.5, U1.19 (FCW[15])
/MPW_20: JC1.6, U1.20 (FCW[16])
/MPW_21: JC1.7, U1.21 (FCW[17])
/MPW_22: JD1.1, U1.22 (FCW[18])
/MPW_23: JD1.2, U1.23 (FCW[19])
/MPW_24: JD1.3, U1.24 (outPhase[0])
/MPW_25: JD1.4, U1.25 (outPhase[1])
/MPW_26: JD1.5, U1.26 (outIsNeg)
/MPW_27: JD1.6, U1.27 (vld)
/MPW_28_C: J2.1, U1.28 (GND)
/MPW_28_P: H1.1, H2.1, J2.2, JD1.7

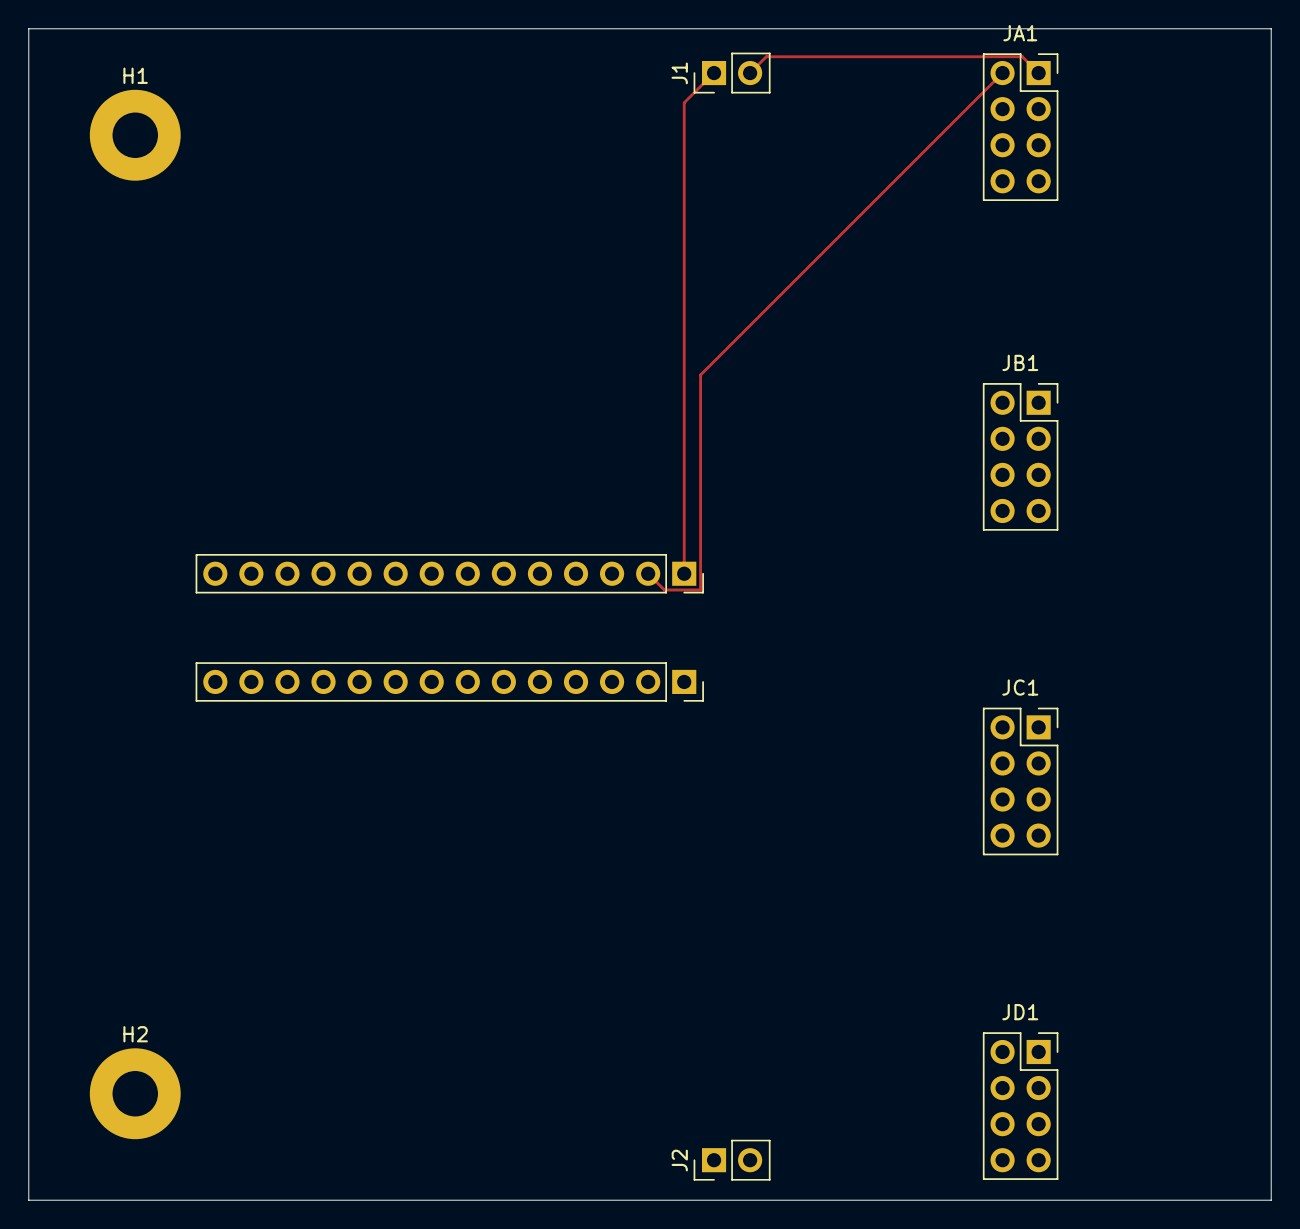
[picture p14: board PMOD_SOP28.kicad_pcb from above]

Board: 2 copper layers, 87.5 x 82.5 mm, 9 parts (0 on the bottom side), 30 nets.

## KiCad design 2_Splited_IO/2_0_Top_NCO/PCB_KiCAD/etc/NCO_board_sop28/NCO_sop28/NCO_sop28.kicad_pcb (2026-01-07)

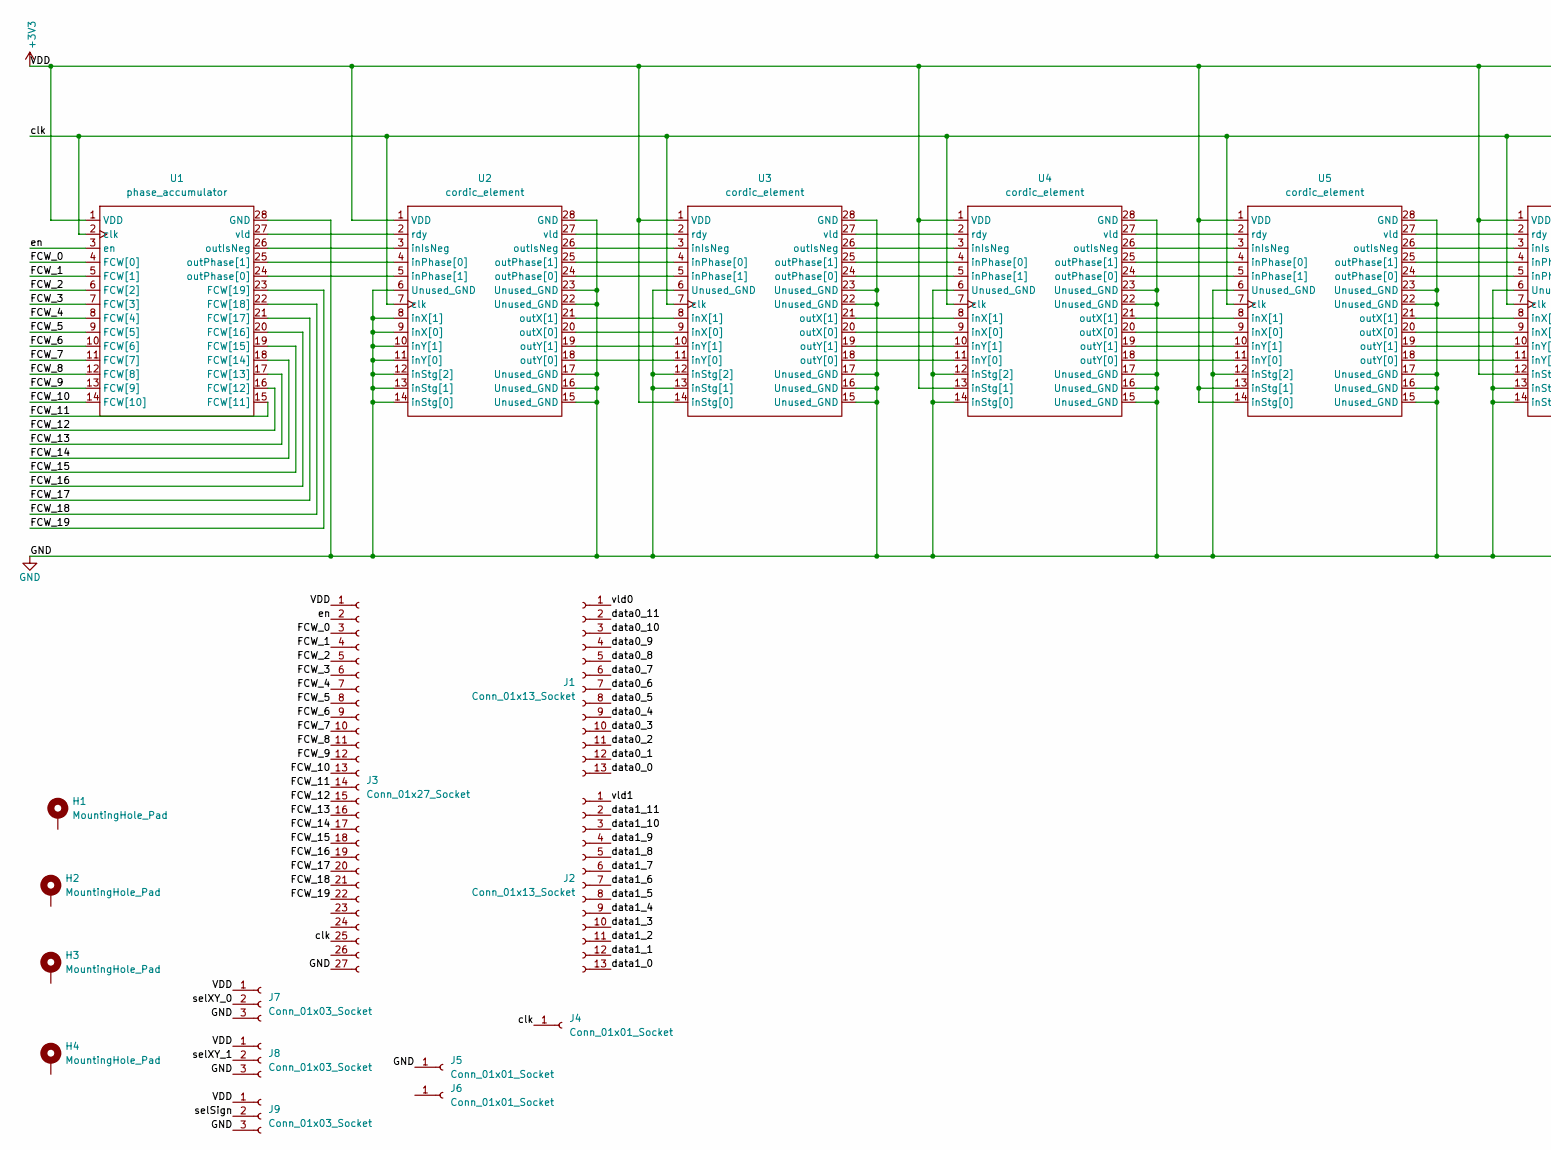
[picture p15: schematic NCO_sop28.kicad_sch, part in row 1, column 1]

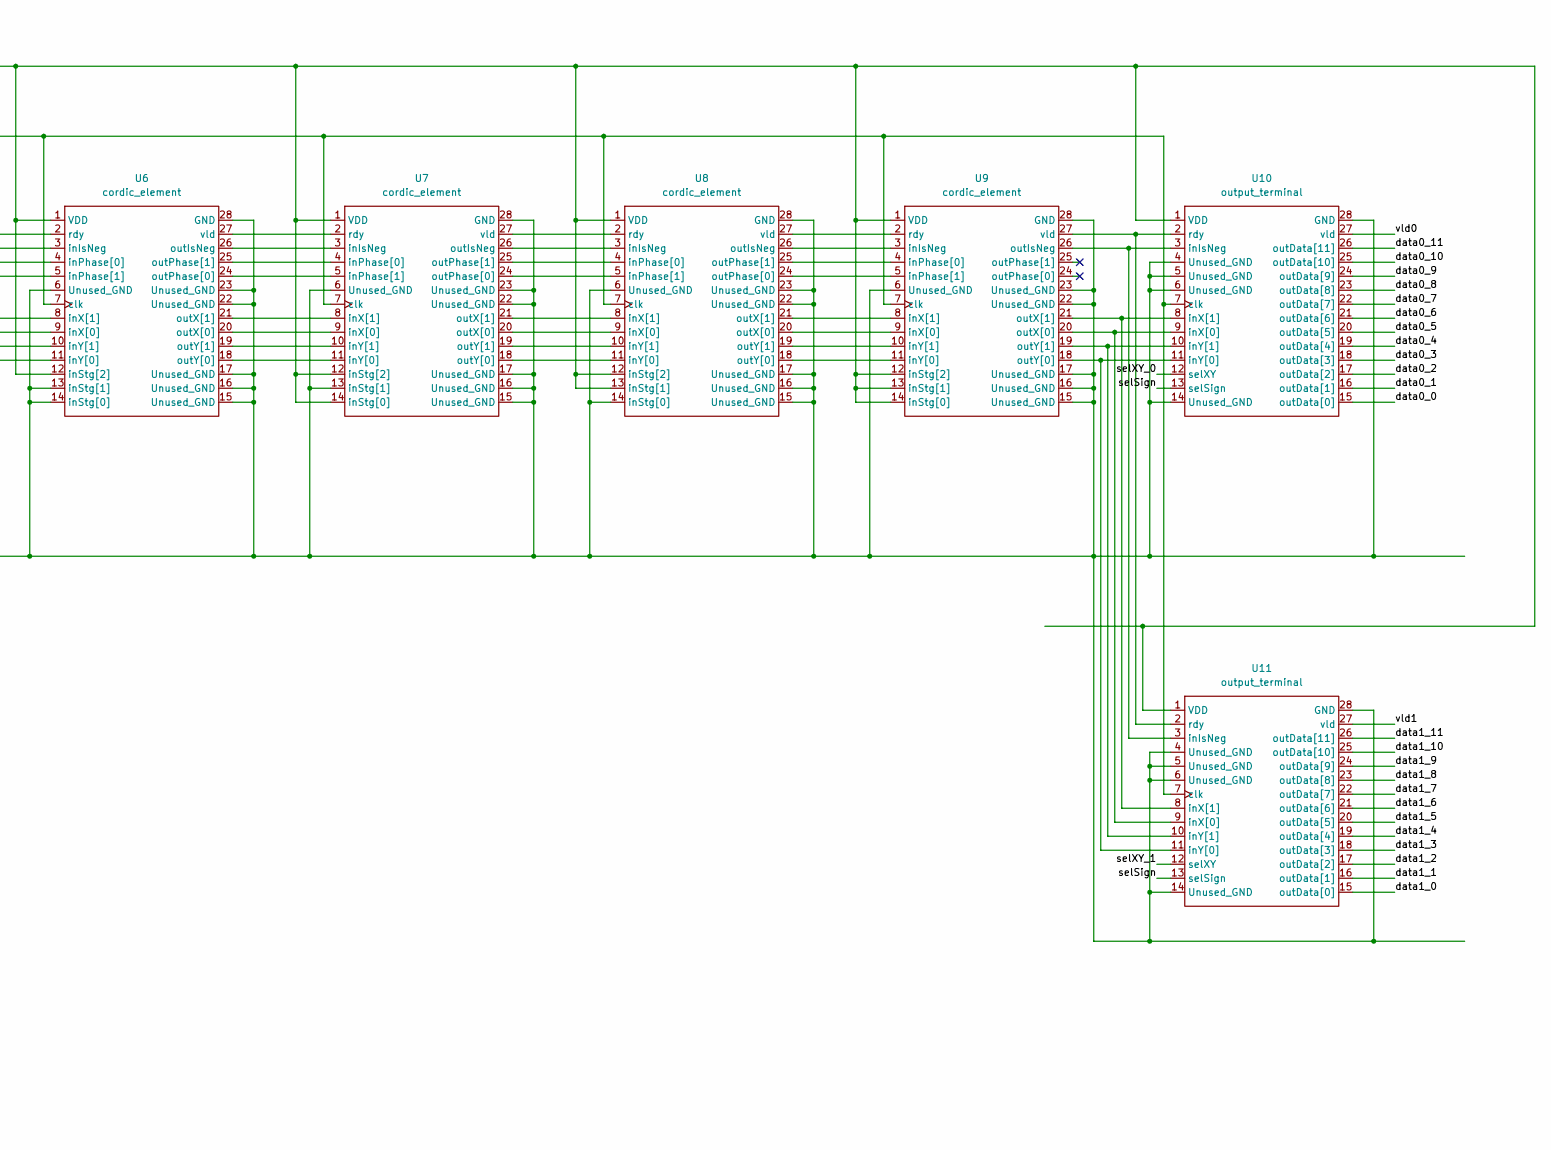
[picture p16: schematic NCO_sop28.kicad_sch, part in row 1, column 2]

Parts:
H1, H2, H3, H4: MountingHole_Pad; MountingHole_3.2mm_M3_Pad
J1, J2: Conn_01x13_Socket; PinHeader_1x13_P2.54mm_Vertical
J3: Conn_01x27_Socket; PinHeader_1x27_P2.54mm_Vertical
J4, J5, J6: Conn_01x01_Socket; PinHeader_1x01_P2.54mm_Vertical
J7, J8, J9: Conn_01x03_Socket; PinHeader_1x03_P2.54mm_Vertical
U1: phase_accumulator; user_socket28_2p54
U2, U3, U4, U5, U6, U7, U8, U9: cordic_element; user_socket28_2p54
U10, U11: output_terminal; user_socket28_2p54

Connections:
+3V3: J3.1, J7.1, J8.1, J9.1, U1.1 (VDD), U2.1 (VDD), U3.1 (VDD), U3.14 (inStg[0]), U4.1 (VDD), U4.13 (inStg[1]), U5.1 (VDD), U5.13 (inStg[1]), U5.14 (inStg[0]), U6.1 (VDD), U6.12 (inStg[2]), U7.1 (VDD), U7.12 (inStg[2]), U7.14 (inStg[0]), U8.1 (VDD), U8.12 (inStg[2]), U8.13 (inStg[1]), U9.1 (VDD), U9.12 (inStg[2]), U9.13 (inStg[1]), U9.14 (inStg[0]), U10.1 (VDD), U11.1 (VDD)
/FCW_0: J3.3, U1.4 (FCW[0])
/FCW_1: J3.4, U1.5 (FCW[1])
/FCW_2: J3.5, U1.6 (FCW[2])
/FCW_3: J3.6, U1.7 (FCW[3])
/FCW_4: J3.7, U1.8 (FCW[4])
/FCW_5: J3.8, U1.9 (FCW[5])
/FCW_6: J3.9, U1.10 (FCW[6])
/FCW_7: J3.10, U1.11 (FCW[7])
/FCW_8: J3.11, U1.12 (FCW[8])
/FCW_9: J3.12, U1.13 (FCW[9])
/FCW_10: J3.13, U1.14 (FCW[10])
/FCW_11: J3.14, U1.15 (FCW[11])
/FCW_12: J3.15, U1.16 (FCW[12])
/FCW_13: J3.16, U1.17 (FCW[13])
/FCW_14: J3.17, U1.18 (FCW[14])
/FCW_15: J3.18, U1.19 (FCW[15])
/FCW_16: J3.19, U1.20 (FCW[16])
/FCW_17: J3.20, U1.21 (FCW[17])
/FCW_18: J3.21, U1.22 (FCW[18])
/FCW_19: J3.22, U1.23 (FCW[19])
/clk: J3.25, J4.1, U1.2 (clk), U2.7 (clk), U3.7 (clk), U4.7 (clk), U5.7 (clk), U6.7 (clk), U7.7 (clk), U8.7 (clk), U9.7 (clk), U10.7 (clk), U11.7 (clk)
/data0_0: J1.13, U10.15 (outData[0])
/data0_1: J1.12, U10.16 (outData[1])
/data0_2: J1.11, U10.17 (outData[2])
/data0_3: J1.10, U10.18 (outData[3])
/data0_4: J1.9, U10.19 (outData[4])
/data0_5: J1.8, U10.20 (outData[5])
/data0_6: J1.7, U10.21 (outData[6])
/data0_7: J1.6, U10.22 (outData[7])
/data0_8: J1.5, U10.23 (outData[8])
/data0_9: J1.4, U10.24 (outData[9])
/data0_10: J1.3, U10.25 (outData[10])
/data0_11: J1.2, U10.26 (outData[11])
/data1_0: J2.13, U11.15 (outData[0])
/data1_1: J2.12, U11.16 (outData[1])
/data1_2: J2.11, U11.17 (outData[2])
/data1_3: J2.10, U11.18 (outData[3])
/data1_4: J2.9, U11.19 (outData[4])
/data1_5: J2.8, U11.20 (outData[5])
/data1_6: J2.7, U11.21 (outData[6])
/data1_7: J2.6, U11.22 (outData[7])
/data1_8: J2.5, U11.23 (outData[8])
/data1_9: J2.4, U11.24 (outData[9])
/data1_10: J2.3, U11.25 (outData[10])
/data1_11: J2.2, U11.26 (outData[11])
/en: J3.2, U1.3 (en)
/selSign: J9.2, U10.13 (selSign), U11.13 (selSign)
/selXY_0: J7.2, U10.12 (selXY)
/selXY_1: J8.2, U11.12 (selXY)
/vld0: J1.1, U10.27 (vld)
/vld1: J2.1, U11.27 (vld)
GND: J3.27, J5.1, J7.3, J8.3, J9.3, U1.28 (GND), U2.6 (Unused_GND), U2.8 (inX[1]), U2.9 (inX[0]), U2.10 (inY[1]), U2.11 (inY[0]), U2.12 (inStg[2]), U2.13 (inStg[1]), U2.14 (inStg[0]), U2.15 (Unused_GND), U2.16 (Unused_GND), U2.17 (Unused_GND), U2.22 (Unused_GND), U2.23 (Unused_GND), U2.28 (GND), U3.6 (Unused_GND), U3.12 (inStg[2]), U3.13 (inStg[1]), U3.15 (Unused_GND), U3.16 (Unused_GND), U3.17 (Unused_GND), U3.22 (Unused_GND), U3.23 (Unused_GND), U3.28 (GND), U4.6 (Unused_GND), U4.12 (inStg[2]), U4.14 (inStg[0]), U4.15 (Unused_GND), U4.16 (Unused_GND), U4.17 (Unused_GND), U4.22 (Unused_GND), U4.23 (Unused_GND), U4.28 (GND), U5.6 (Unused_GND), U5.12 (inStg[2]), U5.15 (Unused_GND), U5.16 (Unused_GND), U5.17 (Unused_GND), U5.22 (Unused_GND), U5.23 (Unused_GND), U5.28 (GND), U6.6 (Unused_GND), U6.13 (inStg[1]), U6.14 (inStg[0]), U6.15 (Unused_GND), U6.16 (Unused_GND), U6.17 (Unused_GND), U6.22 (Unused_GND), U6.23 (Unused_GND), U6.28 (GND), U7.6 (Unused_GND), U7.13 (inStg[1]), U7.15 (Unused_GND), U7.16 (Unused_GND), U7.17 (Unused_GND), U7.22 (Unused_GND), U7.23 (Unused_GND), U7.28 (GND), U8.6 (Unused_GND), U8.14 (inStg[0]), U8.15 (Unused_GND), U8.16 (Unused_GND), U8.17 (Unused_GND), U8.22 (Unused_GND), U8.23 (Unused_GND), U8.28 (GND), U9.6 (Unused_GND), U9.15 (Unused_GND), U9.16 (Unused_GND), U9.17 (Unused_GND), U9.22 (Unused_GND), U9.23 (Unused_GND), U9.28 (GND), U10.4 (Unused_GND), U10.5 (Unused_GND), U10.6 (Unused_GND), U10.14 (Unused_GND), U10.28 (GND), U11.4 (Unused_GND), U11.5 (Unused_GND), U11.6 (Unused_GND), U11.14 (Unused_GND), U11.28 (GND)
unnamed: U1.26 (outIsNeg), U2.3 (inIsNeg)
unnamed: U1.24 (outPhase[0]), U2.5 (inPhase[1])
unnamed: U1.25 (outPhase[1]), U2.4 (inPhase[0])
unnamed: U1.27 (vld), U2.2 (rdy)
unnamed: U2.26 (outIsNeg), U3.3 (inIsNeg)
unnamed: U2.24 (outPhase[0]), U3.5 (inPhase[1])
unnamed: U2.25 (outPhase[1]), U3.4 (inPhase[0])
unnamed: U2.20 (outX[0]), U3.9 (inX[0])
unnamed: U2.21 (outX[1]), U3.8 (inX[1])
unnamed: U2.18 (outY[0]), U3.11 (inY[0])
unnamed: U2.19 (outY[1]), U3.10 (inY[1])
unnamed: U2.27 (vld), U3.2 (rdy)
unnamed: U3.26 (outIsNeg), U4.3 (inIsNeg)
unnamed: U3.24 (outPhase[0]), U4.5 (inPhase[1])
unnamed: U3.25 (outPhase[1]), U4.4 (inPhase[0])
unnamed: U3.20 (outX[0]), U4.9 (inX[0])
unnamed: U3.21 (outX[1]), U4.8 (inX[1])
unnamed: U3.18 (outY[0]), U4.11 (inY[0])
unnamed: U3.19 (outY[1]), U4.10 (inY[1])
unnamed: U3.27 (vld), U4.2 (rdy)
unnamed: U4.26 (outIsNeg), U5.3 (inIsNeg)
unnamed: U4.24 (outPhase[0]), U5.5 (inPhase[1])
unnamed: U4.25 (outPhase[1]), U5.4 (inPhase[0])
unnamed: U4.20 (outX[0]), U5.9 (inX[0])
unnamed: U4.21 (outX[1]), U5.8 (inX[1])
unnamed: U4.18 (outY[0]), U5.11 (inY[0])
unnamed: U4.19 (outY[1]), U5.10 (inY[1])
unnamed: U4.27 (vld), U5.2 (rdy)
unnamed: U5.26 (outIsNeg), U6.3 (inIsNeg)
unnamed: U5.24 (outPhase[0]), U6.5 (inPhase[1])
unnamed: U5.25 (outPhase[1]), U6.4 (inPhase[0])
unnamed: U5.20 (outX[0]), U6.9 (inX[0])
unnamed: U5.21 (outX[1]), U6.8 (inX[1])
unnamed: U5.18 (outY[0]), U6.11 (inY[0])
unnamed: U5.19 (outY[1]), U6.10 (inY[1])
unnamed: U5.27 (vld), U6.2 (rdy)
unnamed: U6.26 (outIsNeg), U7.3 (inIsNeg)
unnamed: U6.24 (outPhase[0]), U7.5 (inPhase[1])
unnamed: U6.25 (outPhase[1]), U7.4 (inPhase[0])
unnamed: U6.20 (outX[0]), U7.9 (inX[0])
unnamed: U6.21 (outX[1]), U7.8 (inX[1])
unnamed: U6.18 (outY[0]), U7.11 (inY[0])
unnamed: U6.19 (outY[1]), U7.10 (inY[1])
unnamed: U6.27 (vld), U7.2 (rdy)
unnamed: U7.26 (outIsNeg), U8.3 (inIsNeg)
unnamed: U7.24 (outPhase[0]), U8.5 (inPhase[1])
unnamed: U7.25 (outPhase[1]), U8.4 (inPhase[0])
unnamed: U7.20 (outX[0]), U8.9 (inX[0])
unnamed: U7.21 (outX[1]), U8.8 (inX[1])
unnamed: U7.18 (outY[0]), U8.11 (inY[0])
unnamed: U7.19 (outY[1]), U8.10 (inY[1])
unnamed: U7.27 (vld), U8.2 (rdy)
unnamed: U8.26 (outIsNeg), U9.3 (inIsNeg)
unnamed: U8.24 (outPhase[0]), U9.5 (inPhase[1])
unnamed: U8.25 (outPhase[1]), U9.4 (inPhase[0])
unnamed: U8.20 (outX[0]), U9.9 (inX[0])
unnamed: U8.21 (outX[1]), U9.8 (inX[1])
unnamed: U8.18 (outY[0]), U9.11 (inY[0])
unnamed: U8.19 (outY[1]), U9.10 (inY[1])
unnamed: U8.27 (vld), U9.2 (rdy)
unnamed: U9.26 (outIsNeg), U10.3 (inIsNeg), U11.3 (inIsNeg)
unnamed: U9.20 (outX[0]), U10.9 (inX[0]), U11.9 (inX[0])
unnamed: U9.21 (outX[1]), U10.8 (inX[1]), U11.8 (inX[1])
unnamed: U9.18 (outY[0]), U10.11 (inY[0]), U11.11 (inY[0])
unnamed: U9.19 (outY[1]), U10.10 (inY[1]), U11.10 (inY[1])
unnamed: U9.27 (vld), U10.2 (rdy), U11.2 (rdy)

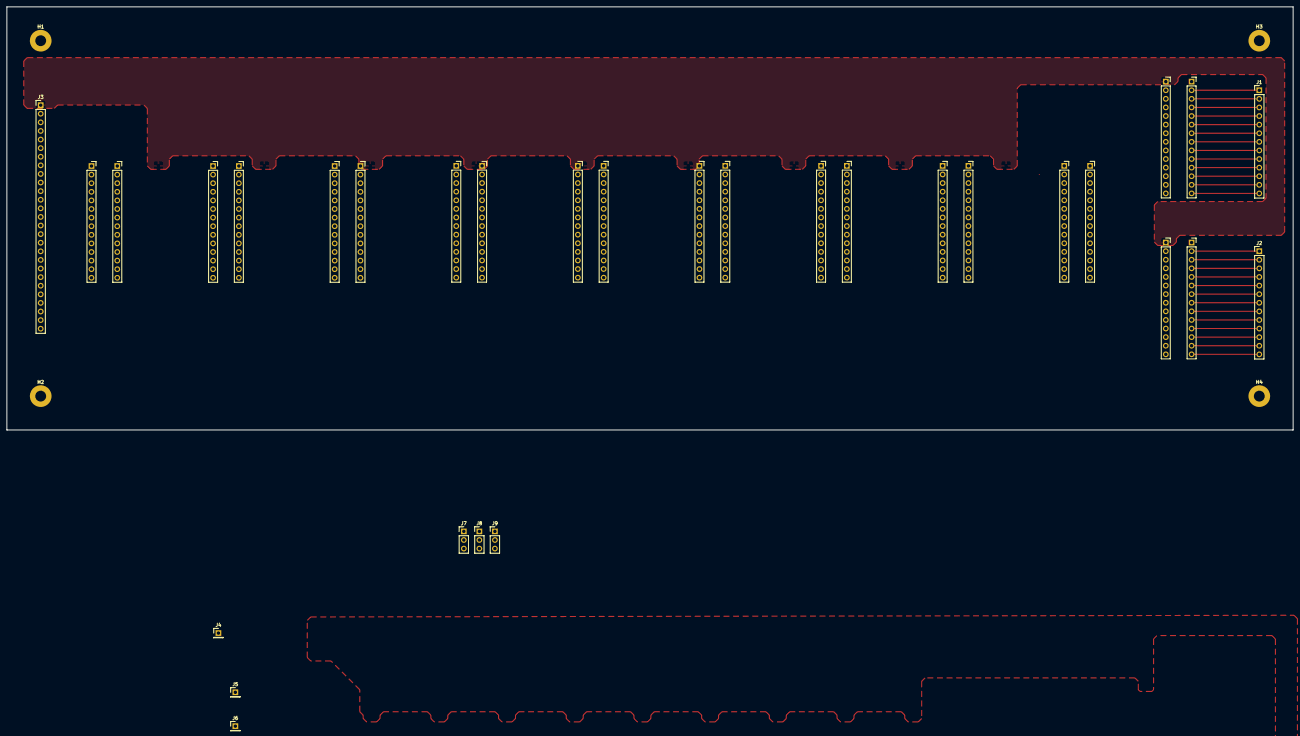
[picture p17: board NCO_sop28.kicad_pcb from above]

Board: 2 copper layers, 380.0 x 125.0 mm, 24 parts (0 on the bottom side), 119 nets.

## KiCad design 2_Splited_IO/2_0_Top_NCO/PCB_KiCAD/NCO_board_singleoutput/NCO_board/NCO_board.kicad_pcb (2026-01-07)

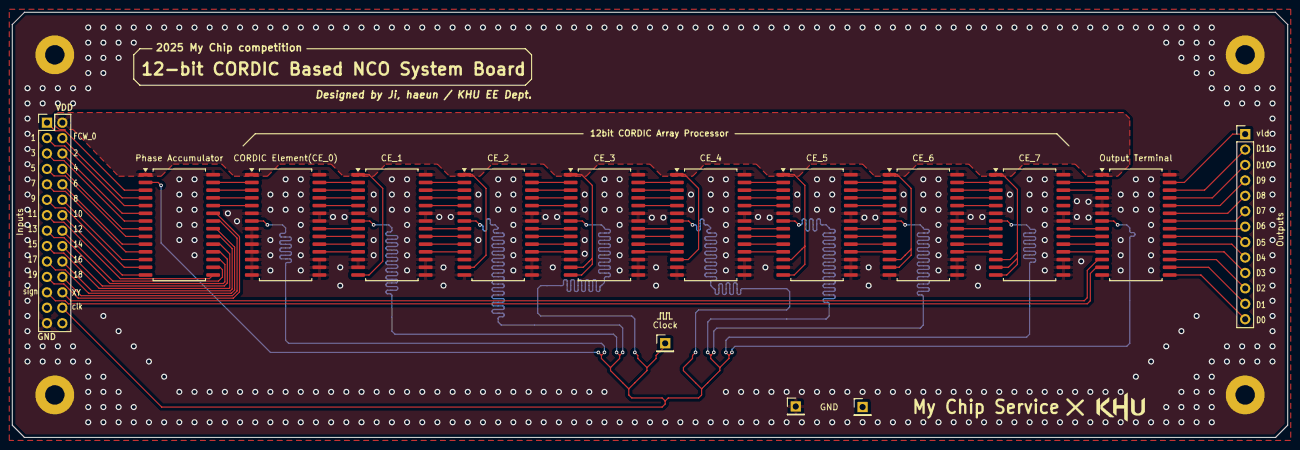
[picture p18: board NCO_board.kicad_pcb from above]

Board: 2 copper layers, 210.0 x 70.0 mm, 19 parts (0 on the bottom side), 105 nets.

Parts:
CE_1, CE_2, CE_3, CE_4, CE_5, CE_6, CE_7: cordic_element; SOP-28_8.4x18.16mm_P1.27mm
CORDIC Element(CE_0): cordic_element; SOP-28_8.4x18.16mm_P1.27mm
Clock: Conn_01x01_Socket; PinHeader_1x01_P2.54mm_Vertical
GND: Conn_01x01_Socket; PinHeader_1x01_P2.54mm_Vertical
H1, H2, H3, H4: MountingHole_Pad; MountingHole_3.2mm_M3_Pad
Inputs: Conn_02x14_Odd_Even; PinHeader_2x14_P2.54mm_Vertical
J6: Conn_01x01_Socket; PinHeader_1x01_P2.54mm_Vertical
Output Terminal: output_terminal; SOP-28_8.4x18.16mm_P1.27mm
Outputs: Conn_01x13_Socket; PinHeader_1x13_P2.54mm_Vertical
Phase Accumulator: phase_accumulator; SOP-28_8.4x18.16mm_P1.27mm

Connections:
+3V3: CE_1.1 (VDD), CE_1.14 (inStg[0]), CE_2.1 (VDD), CE_2.13 (inStg[1]), CE_3.1 (VDD), CE_3.13 (inStg[1]), CE_3.14 (inStg[0]), CE_4.1 (VDD), CE_4.12 (inStg[2]), CE_5.1 (VDD), CE_5.12 (inStg[2]), CE_5.14 (inStg[0]), CE_6.1 (VDD), CE_6.12 (inStg[2]), CE_6.13 (inStg[1]), CE_7.1 (VDD), CE_7.12 (inStg[2]), CE_7.13 (inStg[1]), CE_7.14 (inStg[0]), CORDIC Element(CE_0).1 (VDD), Inputs.2, Output Terminal.1 (VDD), Phase Accumulator.1 (VDD)
/FCW_0: Inputs.4, Phase Accumulator.4 (FCW[0])
/FCW_1: Inputs.3, Phase Accumulator.5 (FCW[1])
/FCW_2: Inputs.6, Phase Accumulator.6 (FCW[2])
/FCW_3: Inputs.5, Phase Accumulator.7 (FCW[3])
/FCW_4: Inputs.8, Phase Accumulator.8 (FCW[4])
/FCW_5: Inputs.7, Phase Accumulator.9 (FCW[5])
/FCW_6: Inputs.10, Phase Accumulator.10 (FCW[6])
/FCW_7: Inputs.9, Phase Accumulator.11 (FCW[7])
/FCW_8: Inputs.12, Phase Accumulator.12 (FCW[8])
/FCW_9: Inputs.11, Phase Accumulator.13 (FCW[9])
/FCW_10: Inputs.14, Phase Accumulator.14 (FCW[10])
/FCW_11: Inputs.13, Phase Accumulator.15 (FCW[11])
/FCW_12: Inputs.16, Phase Accumulator.16 (FCW[12])
/FCW_13: Inputs.15, Phase Accumulator.17 (FCW[13])
/FCW_14: Inputs.18, Phase Accumulator.18 (FCW[14])
/FCW_15: Inputs.17, Phase Accumulator.19 (FCW[15])
/FCW_16: Inputs.20, Phase Accumulator.20 (FCW[16])
/FCW_17: Inputs.19, Phase Accumulator.21 (FCW[17])
/FCW_18: Inputs.22, Phase Accumulator.22 (FCW[18])
/FCW_19: Inputs.21, Phase Accumulator.23 (FCW[19])
/clk: CE_1.7 (clk), CE_2.7 (clk), CE_3.7 (clk), CE_4.7 (clk), CE_5.7 (clk), CE_6.7 (clk), CE_7.7 (clk), CORDIC Element(CE_0).7 (clk), Clock.1, Inputs.26, Output Terminal.7 (clk), Phase Accumulator.2 (clk)
/data_0: Output Terminal.15 (outData[0]), Outputs.13
/data_1: Output Terminal.16 (outData[1]), Outputs.12
/data_2: Output Terminal.17 (outData[2]), Outputs.11
/data_3: Output Terminal.18 (outData[3]), Outputs.10
/data_4: Output Terminal.19 (outData[4]), Outputs.9
/data_5: Output Terminal.20 (outData[5]), Outputs.8
/data_6: Output Terminal.21 (outData[6]), Outputs.7
/data_7: Output Terminal.22 (outData[7]), Outputs.6
/data_8: Output Terminal.23 (outData[8]), Outputs.5
/data_9: Output Terminal.24 (outData[9]), Outputs.4
/data_10: Output Terminal.25 (outData[10]), Outputs.3
/data_11: Output Terminal.26 (outData[11]), Outputs.2
/en: Inputs.1, Phase Accumulator.3 (en)
/selSign: Inputs.23, Output Terminal.13 (selSign)
/selXY: Inputs.24, Output Terminal.12 (selXY)
/vld: Output Terminal.27 (vld), Outputs.1
GND: CE_1.6 (Unused_GND), CE_1.12 (inStg[2]), CE_1.13 (inStg[1]), CE_1.15 (Unused_GND), CE_1.16 (Unused_GND), CE_1.17 (Unused_GND), CE_1.22 (Unused_GND), CE_1.23 (Unused_GND), CE_1.28 (GND), CE_2.6 (Unused_GND), CE_2.12 (inStg[2]), CE_2.14 (inStg[0]), CE_2.15 (Unused_GND), CE_2.16 (Unused_GND), CE_2.17 (Unused_GND), CE_2.22 (Unused_GND), CE_2.23 (Unused_GND), CE_2.28 (GND), CE_3.6 (Unused_GND), CE_3.12 (inStg[2]), CE_3.15 (Unused_GND), CE_3.16 (Unused_GND), CE_3.17 (Unused_GND), CE_3.22 (Unused_GND), CE_3.23 (Unused_GND), CE_3.28 (GND), CE_4.6 (Unused_GND), CE_4.13 (inStg[1]), CE_4.14 (inStg[0]), CE_4.15 (Unused_GND), CE_4.16 (Unused_GND), CE_4.17 (Unused_GND), CE_4.22 (Unused_GND), CE_4.23 (Unused_GND), CE_4.28 (GND), CE_5.6 (Unused_GND), CE_5.13 (inStg[1]), CE_5.15 (Unused_GND), CE_5.16 (Unused_GND), CE_5.17 (Unused_GND), CE_5.22 (Unused_GND), CE_5.23 (Unused_GND), CE_5.28 (GND), CE_6.6 (Unused_GND), CE_6.14 (inStg[0]), CE_6.15 (Unused_GND), CE_6.16 (Unused_GND), CE_6.17 (Unused_GND), CE_6.22 (Unused_GND), CE_6.23 (Unused_GND), CE_6.28 (GND), CE_7.6 (Unused_GND), CE_7.15 (Unused_GND), CE_7.16 (Unused_GND), CE_7.17 (Unused_GND), CE_7.22 (Unused_GND), CE_7.23 (Unused_GND), CE_7.28 (GND), CORDIC Element(CE_0).6 (Unused_GND), CORDIC Element(CE_0).8 (inX[1]), CORDIC Element(CE_0).9 (inX[0]), CORDIC Element(CE_0).10 (inY[1]), CORDIC Element(CE_0).11 (inY[0]), CORDIC Element(CE_0).12 (inStg[2]), CORDIC Element(CE_0).13 (inStg[1]), CORDIC Element(CE_0).14 (inStg[0]), CORDIC Element(CE_0).15 (Unused_GND), CORDIC Element(CE_0).16 (Unused_GND), CORDIC Element(CE_0).17 (Unused_GND), CORDIC Element(CE_0).22 (Unused_GND), CORDIC Element(CE_0).23 (Unused_GND), CORDIC Element(CE_0).28 (GND), GND.1, H1.1, H2.1, H3.1, H4.1, Inputs.27, Output Terminal.4 (Unused_GND), Output Terminal.5 (Unused_GND), Output Terminal.6 (Unused_GND), Output Terminal.14 (Unused_GND), Output Terminal.28 (GND), Phase Accumulator.28 (GND)
unnamed: CORDIC Element(CE_0).3 (inIsNeg), Phase Accumulator.26 (outIsNeg)
unnamed: CORDIC Element(CE_0).5 (inPhase[1]), Phase Accumulator.24 (outPhase[0])
unnamed: CORDIC Element(CE_0).4 (inPhase[0]), Phase Accumulator.25 (outPhase[1])
unnamed: CORDIC Element(CE_0).2 (rdy), Phase Accumulator.27 (vld)
unnamed: CE_1.3 (inIsNeg), CORDIC Element(CE_0).26 (outIsNeg)
unnamed: CE_1.5 (inPhase[1]), CORDIC Element(CE_0).24 (outPhase[0])
unnamed: CE_1.4 (inPhase[0]), CORDIC Element(CE_0).25 (outPhase[1])
unnamed: CE_1.9 (inX[0]), CORDIC Element(CE_0).20 (outX[0])
unnamed: CE_1.8 (inX[1]), CORDIC Element(CE_0).21 (outX[1])
unnamed: CE_1.11 (inY[0]), CORDIC Element(CE_0).18 (outY[0])
unnamed: CE_1.10 (inY[1]), CORDIC Element(CE_0).19 (outY[1])
unnamed: CE_1.2 (rdy), CORDIC Element(CE_0).27 (vld)
unnamed: CE_1.26 (outIsNeg), CE_2.3 (inIsNeg)
unnamed: CE_1.24 (outPhase[0]), CE_2.5 (inPhase[1])
unnamed: CE_1.25 (outPhase[1]), CE_2.4 (inPhase[0])
unnamed: CE_1.20 (outX[0]), CE_2.9 (inX[0])
unnamed: CE_1.21 (outX[1]), CE_2.8 (inX[1])
unnamed: CE_1.18 (outY[0]), CE_2.11 (inY[0])
unnamed: CE_1.19 (outY[1]), CE_2.10 (inY[1])
unnamed: CE_1.27 (vld), CE_2.2 (rdy)
unnamed: CE_2.26 (outIsNeg), CE_3.3 (inIsNeg)
unnamed: CE_2.24 (outPhase[0]), CE_3.5 (inPhase[1])
unnamed: CE_2.25 (outPhase[1]), CE_3.4 (inPhase[0])
unnamed: CE_2.20 (outX[0]), CE_3.9 (inX[0])
unnamed: CE_2.21 (outX[1]), CE_3.8 (inX[1])
unnamed: CE_2.18 (outY[0]), CE_3.11 (inY[0])
unnamed: CE_2.19 (outY[1]), CE_3.10 (inY[1])
unnamed: CE_2.27 (vld), CE_3.2 (rdy)
unnamed: CE_3.26 (outIsNeg), CE_4.3 (inIsNeg)
unnamed: CE_3.24 (outPhase[0]), CE_4.5 (inPhase[1])
unnamed: CE_3.25 (outPhase[1]), CE_4.4 (inPhase[0])
unnamed: CE_3.20 (outX[0]), CE_4.9 (inX[0])
unnamed: CE_3.21 (outX[1]), CE_4.8 (inX[1])
unnamed: CE_3.18 (outY[0]), CE_4.11 (inY[0])
unnamed: CE_3.19 (outY[1]), CE_4.10 (inY[1])
unnamed: CE_3.27 (vld), CE_4.2 (rdy)
unnamed: CE_4.26 (outIsNeg), CE_5.3 (inIsNeg)
unnamed: CE_4.24 (outPhase[0]), CE_5.5 (inPhase[1])
unnamed: CE_4.25 (outPhase[1]), CE_5.4 (inPhase[0])
unnamed: CE_4.20 (outX[0]), CE_5.9 (inX[0])
unnamed: CE_4.21 (outX[1]), CE_5.8 (inX[1])
unnamed: CE_4.18 (outY[0]), CE_5.11 (inY[0])
unnamed: CE_4.19 (outY[1]), CE_5.10 (inY[1])
unnamed: CE_4.27 (vld), CE_5.2 (rdy)
unnamed: CE_5.26 (outIsNeg), CE_6.3 (inIsNeg)
unnamed: CE_5.24 (outPhase[0]), CE_6.5 (inPhase[1])
unnamed: CE_5.25 (outPhase[1]), CE_6.4 (inPhase[0])
unnamed: CE_5.20 (outX[0]), CE_6.9 (inX[0])
unnamed: CE_5.21 (outX[1]), CE_6.8 (inX[1])
unnamed: CE_5.18 (outY[0]), CE_6.11 (inY[0])
unnamed: CE_5.19 (outY[1]), CE_6.10 (inY[1])
unnamed: CE_5.27 (vld), CE_6.2 (rdy)
unnamed: CE_6.26 (outIsNeg), CE_7.3 (inIsNeg)
unnamed: CE_6.24 (outPhase[0]), CE_7.5 (inPhase[1])
unnamed: CE_6.25 (outPhase[1]), CE_7.4 (inPhase[0])
unnamed: CE_6.20 (outX[0]), CE_7.9 (inX[0])
unnamed: CE_6.21 (outX[1]), CE_7.8 (inX[1])
unnamed: CE_6.18 (outY[0]), CE_7.11 (inY[0])
unnamed: CE_6.19 (outY[1]), CE_7.10 (inY[1])
unnamed: CE_6.27 (vld), CE_7.2 (rdy)
unnamed: CE_7.26 (outIsNeg), Output Terminal.3 (inIsNeg)
unnamed: CE_7.20 (outX[0]), Output Terminal.9 (inX[0])
unnamed: CE_7.21 (outX[1]), Output Terminal.8 (inX[1])
unnamed: CE_7.18 (outY[0]), Output Terminal.11 (inY[0])
unnamed: CE_7.19 (outY[1]), Output Terminal.10 (inY[1])
unnamed: CE_7.27 (vld), Output Terminal.2 (rdy)

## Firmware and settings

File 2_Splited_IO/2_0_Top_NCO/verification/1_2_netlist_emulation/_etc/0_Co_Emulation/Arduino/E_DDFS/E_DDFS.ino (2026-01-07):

/*
  'BOOTH4' Co-Emulation interface

  Emulator Pin Mapping:
    Arduino DUE & Arty A7-100 & Verilog RTL
  --------------- ---------- ----------- -----------
  SAM3X8E/Digital Pmod /FPGA  SOP28       BOOTH4
  --------------- ---------- ----------- -----------
   PB26/22        JD-4 /F3    28          FCW[19]
   PA14/23        JD-10/G2    27          FCW[18]
   PA15/24        JD-3 /F4    26          FCW[17]
   PD0 /25        JD-9 /H2    25          FCW[16]
   PD1 /26        JD-2 /D3    24          FCW[15]
   PD2 /27        JD-8 /D2    23          FCW[14]
   PD3 /28        JD-1 /D4    22          FCW[13]
   PD6 /29        JD-7 /E2    -           FCW[12]

   PD9 /30        JC-4 /V11   21          FCW[11]
   PA7 /31        JC-10/U13   20          FCW[10]
   PD10/32        JC-3 /V10   19          FCW[9]
   PC1 /33        JC-9 /T13   18          FCW[8]
   PC2 /34        JC-2 /V12   17          FCW[7]
   PC3 /35        JC-8 /V14   16          FCW[6]
   PC4 /36        JC-1 /U12   15          FCW[5]
   PC5 /37        JC-7 /U14   -           FCW[4]

   PC6 /38        JB-4 /C15   14          FCW[3]
   PC7 /39        JB-10/J15   13          FCW[2] 
   PC8 /40        JB-3 /D15   12          FCW[1]
   PC9 /41        JB-9 /K15   11          FCW[0]
   PA19/42        JB-2 /E16   10          Dout[11]
   PA20/43        JB-8 /J18   09          Dout[10]
   PC19/44        JB-1 /E15   08          Dout[9]
   PC18/45        JB-7 /J17   -           Dout[8]

   PC17/46        JA-4 /D12   07          Dout[7]
   PC16/47        JA-10/K16   06          Dout[6]
   PC15/48        JA-3 /A11   05          Dout[5]
   PC14/49        JA-9 /A18   04          Dout[4]
   PC13/50        JA-2 /B11   03          Dout[3]
   PC12/51        JA-8 /B18   02          Dout[2]
   PB21/52        JA-1 /G13   01          Dout[1]
   PB14/53        JA-7 /D13   -           Dout[0]
*/
#define DPIN_CLK 	13 
#define DPIN_En 	12 
#define DPIN_SEL	11
#define DPIN_VLD	10	

#define DPIN_FCW19 	22 
#define DPIN_FCW18 	23 
#define DPIN_FCW17 	24  
#define DPIN_FCW16 	25  
#define DPIN_FCW15 	26  
#define DPIN_FCW14 	27
#define DPIN_FCW13 	28
#define DPIN_FCW12 	29

#define DPIN_FCW11	30 
#define DPIN_FCW10 	31
#define DPIN_FCW9 	32
#define DPIN_FCW8 	33
#define DPIN_FCW7 	34
#define DPIN_FCW6 	35
#define DPIN_FCW5 	36
#define DPIN_FCW4 	37

#define DPIN_FCW3 	38
#define DPIN_FCW2 	39
#define DPIN_FCW1 	40
#define DPIN_FCW0 	41
//---------------------
#define DPIN_Dout11 42
#define DPIN_Dout10 43
#define DPIN_Dout9 	44
#define DPIN_Dout8 	45

#define DPIN_Dout7 	46
#define DPIN_Dout6 	47
#define DPIN_Dout5 	48
#define DPIN_Dout4 	49
#define DPIN_Dout3 	50
#define DPIN_Dout2 	51
#define DPIN_Dout1 	52
#define DPIN_Dout0 	53

//--------------------------------------------------------------------
void establishContact()
{
  while (Serial.available() <= 0)
  {
    Serial.print('A');  // send a capital A
    delay(300);
    if (Serial.read()==(int)'A')
      break;
  }
}
//---------------------------------------------------------------------
void setup()
{
  // start serial port at 9600 bps:
  Serial.begin(115200);
  while (!Serial)
  {
    ;  // wait for serial port to connect. Needed for native USB port only
  }
  establishContact();  // send a byte to establish contact until receiver responds

  // Set all Arduino's digital pins as INPUT mode
  for (uint32_t dPins = 22; dPins < 54; dPins++)
    pinMode( dPins, INPUT);

  // Set Arduino's digital pins to output mode
  //    for DUT's input ports
  pinMode(DPIN_CLK,	OUTPUT);
  pinMode(DPIN_En,	OUTPUT);
  pinMode(DPIN_SEL,	OUTPUT);
  pinMode(DPIN_FCW19, OUTPUT);
  pinMode(DPIN_FCW18, OUTPUT);
  pinMode(DPIN_FCW17, OUTPUT);
  pinMode(DPIN_FCW16, OUTPUT);
  pinMode(DPIN_FCW15, OUTPUT);
  pinMode(DPIN_FCW14, OUTPUT);
  pinMode(DPIN_FCW13, OUTPUT);
  pinMode(DPIN_FCW12, OUTPUT);
  pinMode(DPIN_FCW11, OUTPUT);
  pinMode(DPIN_FCW10, OUTPUT);
  pinMode(DPIN_FCW9, OUTPUT);
  pinMode(DPIN_FCW8, OUTPUT);
  pinMode(DPIN_FCW7, OUTPUT);
  pinMode(DPIN_FCW6, OUTPUT);
  pinMode(DPIN_FCW5, OUTPUT);
  pinMode(DPIN_FCW4, OUTPUT);
  pinMode(DPIN_FCW3, OUTPUT);
  pinMode(DPIN_FCW2, OUTPUT);
  pinMode(DPIN_FCW1, OUTPUT);
  pinMode(DPIN_FCW0, OUTPUT);

  // Preset for output pins
  digitalWrite(DPIN_CLK, LOW);
  digitalWrite(DPIN_En, LOW);
  digitalWrite(DPIN_SEL, LOW);
  
  digitalWrite(DPIN_FCW19, LOW);
  digitalWrite(DPIN_FCW18, LOW);
  digitalWrite(DPIN_FCW17, LOW);
  digitalWrite(DPIN_FCW16, LOW);
  digitalWrite(DPIN_FCW15, LOW);
  digitalWrite(DPIN_FCW14, LOW);
  digitalWrite(DPIN_FCW13, LOW);
  digitalWrite(DPIN_FCW12, LOW);
  digitalWrite(DPIN_FCW11, LOW);
  digitalWrite(DPIN_FCW10, LOW);
  digitalWrite(DPIN_FCW9, LOW);
  digitalWrite(DPIN_FCW8, LOW);
  digitalWrite(DPIN_FCW7, LOW);
  digitalWrite(DPIN_FCW6, LOW);
  digitalWrite(DPIN_FCW5, LOW);
  digitalWrite(DPIN_FCW4, LOW);
  digitalWrite(DPIN_FCW3, LOW);
  digitalWrite(DPIN_FCW2, LOW);
  digitalWrite(DPIN_FCW1, LOW);
  digitalWrite(DPIN_FCW0, LOW);

  // Monitoring ......
  pinMode(LED_BUILTIN, OUTPUT);
  digitalWrite(LED_BUILTIN, HIGH);
}
//---------------------------------------------------------------------
#define N_RX  3
uint8_t rxBuf[N_RX];
// rxBuf[0]: x|x|x|x|x|START|RESET|CLK
// rxBuf[1]: Y[3:0]|X[3:0]
void RxPacket()
{
  int rxByte;

  while(true)
  {
    // Resceive test vector from SC testbench
    if (Serial.available() >= N_RX)
    {
      for(int i=0; i<N_RX; i++)
      {
        rxByte = Serial.read();
        rxBuf[i] = (uint8_t)rxByte;
      }
      // Apply received test vector to DUT's input ports
      // Set IO firstly
      //digitalWrite(DPIN_CLK,	(rxBuf[0]&0x80)? HIGH:LOW);
      digitalWrite(DPIN_En, 	(rxBuf[0]&0x40)? HIGH:LOW);
      digitalWrite(DPIN_SEL,	(rxBuf[0]&0x20)? HIGH:LOW);
	  
      digitalWrite(DPIN_FCW19, 	(rxBuf[0]&0x08)? HIGH:LOW);
      digitalWrite(DPIN_FCW18, 	(rxBuf[0]&0x04)? HIGH:LOW);
      digitalWrite(DPIN_FCW17, 	(rxBuf[0]&0x02)? HIGH:LOW);
      digitalWrite(DPIN_FCW16, 	(rxBuf[0]&0x01)? HIGH:LOW);
      digitalWrite(DPIN_FCW15, 	(rxBuf[1]&0x80)? HIGH:LOW);
      digitalWrite(DPIN_FCW14, 	(rxBuf[1]&0x40)? HIGH:LOW);
      digitalWrite(DPIN_FCW13, 	(rxBuf[1]&0x20)? HIGH:LOW);
	    digitalWrite(DPIN_FCW12, 	(rxBuf[1]&0x10)? HIGH:LOW);
      digitalWrite(DPIN_FCW11, 	(rxBuf[1]&0x08)? HIGH:LOW);
      digitalWrite(DPIN_FCW10, 	(rxBuf[1]&0x04)? HIGH:LOW);
      digitalWrite(DPIN_FCW9,	(rxBuf[1]&0x02)? HIGH:LOW);
      digitalWrite(DPIN_FCW8,	(rxBuf[1]&0x01)? HIGH:LOW);
      digitalWrite(DPIN_FCW7,	(rxBuf[2]&0x80)? HIGH:LOW);
      digitalWrite(DPIN_FCW6,	(rxBuf[2]&0x40)? HIGH:LOW);
      digitalWrite(DPIN_FCW5,	(rxBuf[2]&0x20)? HIGH:LOW);
	    digitalWrite(DPIN_FCW4,	(rxBuf[2]&0x10)? HIGH:LOW);
      digitalWrite(DPIN_FCW3,	(rxBuf[2]&0x08)? HIGH:LOW);
      digitalWrite(DPIN_FCW2,	(rxBuf[2]&0x04)? HIGH:LOW);
      digitalWrite(DPIN_FCW1,	(rxBuf[2]&0x02)? HIGH:LOW);
      digitalWrite(DPIN_FCW0,	(rxBuf[2]&0x01)? HIGH:LOW);
	  
      // Then Clocking
      digitalWrite(DPIN_CLK,	(rxBuf[0]&0x80)? HIGH:LOW);

      return;
    }
  }
}
//---------------------------------------------------------------------
#define N_TX  2
uint8_t txBuf[N_RX];
// txBuf[0]: x|x|x|x|x|x|x|VALID
// txBuf[1]: Z[7:0]
void TxPacket()
{
  int txByte;

  while(1)
  {
    // Capture DUT's output ports
    txBuf[0] = 	digitalRead(DPIN_VLD) 	<< 7 |
				digitalRead(DPIN_Dout11)<< 3 |
				digitalRead(DPIN_Dout10)<< 2 |
				digitalRead(DPIN_Dout9)	<< 1 |
				digitalRead(DPIN_Dout8)	<< 0 ;
    txBuf[1] = 	digitalRead(DPIN_Dout7) << 7 |
				digitalRead(DPIN_Dout6) << 6 |
				digitalRead(DPIN_Dout5) << 5 |
				digitalRead(DPIN_Dout4) << 4 |
				digitalRead(DPIN_Dout3) << 3 |
				digitalRead(DPIN_Dout2) << 2 |
				digitalRead(DPIN_Dout1) << 1 |
				digitalRead(DPIN_Dout0) << 0;
    // Send ports' captured value back to SC testbench
    if (Serial.availableForWrite() >= N_TX)
    {
      for(int i=0; i<N_TX; i++)
      {
        txByte = (int)txBuf[i];
        Serial.write(txByte);
      }

      return;
    }
  }
}
//----------------------------------------------------------------
void loop()
{
  RxPacket();
  TxPacket();
  digitalWrite(LED_BUILTIN, (rxBuf[0]&0x80)? HIGH:LOW);
}

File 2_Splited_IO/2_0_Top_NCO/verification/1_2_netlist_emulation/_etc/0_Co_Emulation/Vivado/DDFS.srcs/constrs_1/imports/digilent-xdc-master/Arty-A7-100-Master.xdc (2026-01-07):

## This file is a general .xdc for the Arty A7-100 Rev. D and Rev. E
## To use it in a project:
## - uncomment the lines corresponding to used pins
## - rename the used ports (in each line, after get_ports) according to the top level signal names in the project

## Clock signal
#set_property -dict { PACKAGE_PIN E3    IOSTANDARD LVCMOS33 } [get_ports { CLK100MHZ }]; #IO_L12P_T1_MRCC_35 Sch=gclk[100]
#create_clock -add -name sys_clk_pin -period 10.00 -waveform {0 5} [get_ports { CLK100MHZ }];

## Switches
#set_property -dict { PACKAGE_PIN A8    IOSTANDARD LVCMOS33 } [get_ports { sw[0] }]; #IO_L12N_T1_MRCC_16 Sch=sw[0]
#set_property -dict { PACKAGE_PIN C11   IOSTANDARD LVCMOS33 } [get_ports { sw[1] }]; #IO_L13P_T2_MRCC_16 Sch=sw[1]
#set_property -dict { PACKAGE_PIN C10   IOSTANDARD LVCMOS33 } [get_ports { sw[2] }]; #IO_L13N_T2_MRCC_16 Sch=sw[2]
#set_property -dict { PACKAGE_PIN A10   IOSTANDARD LVCMOS33 } [get_ports { sw[3] }]; #IO_L14P_T2_SRCC_16 Sch=sw[3]

## RGB LEDs
#set_property -dict { PACKAGE_PIN E1    IOSTANDARD LVCMOS33 } [get_ports { led0_b }]; #IO_L18N_T2_35 Sch=led0_b
#set_property -dict { PACKAGE_PIN F6    IOSTANDARD LVCMOS33 } [get_ports { led0_g }]; #IO_L19N_T3_VREF_35 Sch=led0_g
#set_property -dict { PACKAGE_PIN G6    IOSTANDARD LVCMOS33 } [get_ports { led0_r }]; #IO_L19P_T3_35 Sch=led0_r
#set_property -dict { PACKAGE_PIN G4    IOSTANDARD LVCMOS33 } [get_ports { led1_b }]; #IO_L20P_T3_35 Sch=led1_b
#set_property -dict { PACKAGE_PIN J4    IOSTANDARD LVCMOS33 } [get_ports { led1_g }]; #IO_L21P_T3_DQS_35 Sch=led1_g
#set_property -dict { PACKAGE_PIN G3    IOSTANDARD LVCMOS33 } [get_ports { led1_r }]; #IO_L20N_T3_35 Sch=led1_r
#set_property -dict { PACKAGE_PIN H4    IOSTANDARD LVCMOS33 } [get_ports { led2_b }]; #IO_L21N_T3_DQS_35 Sch=led2_b
#set_property -dict { PACKAGE_PIN J2    IOSTANDARD LVCMOS33 } [get_ports { led2_g }]; #IO_L22N_T3_35 Sch=led2_g
#set_property -dict { PACKAGE_PIN J3    IOSTANDARD LVCMOS33 } [get_ports { led2_r }]; #IO_L22P_T3_35 Sch=led2_r
#set_property -dict { PACKAGE_PIN K2    IOSTANDARD LVCMOS33 } [get_ports { led3_b }]; #IO_L23P_T3_35 Sch=led3_b
#set_property -dict { PACKAGE_PIN H6    IOSTANDARD LVCMOS33 } [get_ports { led3_g }]; #IO_L24P_T3_35 Sch=led3_g
#set_property -dict { PACKAGE_PIN K1    IOSTANDARD LVCMOS33 } [get_ports { led3_r }]; #IO_L23N_T3_35 Sch=led3_r

## LEDs
#set_property -dict { PACKAGE_PIN H5    IOSTANDARD LVCMOS33 } [get_ports { led[0] }]; #IO_L24N_T3_35 Sch=led[4]
#set_property -dict { PACKAGE_PIN J5    IOSTANDARD LVCMOS33 } [get_ports { led[1] }]; #IO_25_35 Sch=led[5]
#set_property -dict { PACKAGE_PIN T9    IOSTANDARD LVCMOS33 } [get_ports { led[2] }]; #IO_L24P_T3_A01_D17_14 Sch=led[6]
#set_property -dict { PACKAGE_PIN T10   IOSTANDARD LVCMOS33 } [get_ports { led[3] }]; #IO_L24N_T3_A00_D16_14 Sch=led[7]

## Buttons
#set_property -dict { PACKAGE_PIN D9    IOSTANDARD LVCMOS33 } [get_ports { btn[0] }]; #IO_L6N_T0_VREF_16 Sch=btn[0]
#set_property -dict { PACKAGE_PIN C9    IOSTANDARD LVCMOS33 } [get_ports { btn[1] }]; #IO_L11P_T1_SRCC_16 Sch=btn[1]
#set_property -dict { PACKAGE_PIN B9    IOSTANDARD LVCMOS33 } [get_ports { btn[2] }]; #IO_L11N_T1_SRCC_16 Sch=btn[2]
#set_property -dict { PACKAGE_PIN B8    IOSTANDARD LVCMOS33 } [get_ports { btn[3] }]; #IO_L12P_T1_MRCC_16 Sch=btn[3]

## Pmod Header JA
set_property -dict { PACKAGE_PIN G13   IOSTANDARD LVCMOS33 } [get_ports { Dout[1] }]; #IO_0_15 Sch=ja[1]
set_property -dict { PACKAGE_PIN B11   IOSTANDARD LVCMOS33 } [get_ports { Dout[3] }]; #IO_L4P_T0_15 Sch=ja[2]
set_property -dict { PACKAGE_PIN A11   IOSTANDARD LVCMOS33 } [get_ports { Dout[5] }]; #IO_L4N_T0_15 Sch=ja[3]
set_property -dict { PACKAGE_PIN D12   IOSTANDARD LVCMOS33 } [get_ports { Dout[7] }]; #IO_L6P_T0_15 Sch=ja[4]
set_property -dict { PACKAGE_PIN D13   IOSTANDARD LVCMOS33 } [get_ports { Dout[0] }]; #IO_L6N_T0_VREF_15 Sch=ja[7]
set_property -dict { PACKAGE_PIN B18   IOSTANDARD LVCMOS33 } [get_ports { Dout[2] }]; #IO_L10P_T1_AD11P_15 Sch=ja[8]
set_property -dict { PACKAGE_PIN A18   IOSTANDARD LVCMOS33 } [get_ports { Dout[4] }]; #IO_L10N_T1_AD11N_15 Sch=ja[9]
set_property -dict { PACKAGE_PIN K16   IOSTANDARD LVCMOS33 } [get_ports { Dout[6] }]; #IO_25_15 Sch=ja[10]
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

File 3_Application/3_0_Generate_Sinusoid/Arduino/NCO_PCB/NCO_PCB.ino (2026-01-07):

#define CLK   24
#define EN    53
#define MODE  29
#define SELXY 28

#define FCW00 50
#define FCW01 51
#define FCW02 48
#define FCW03 49
#define FCW04 46
#define FCW05 47
#define FCW06 44
#define FCW07 45
#define FCW08 42
#define FCW09 43
#define FCW10 40
#define FCW11 41
#define FCW12 38
#define FCW13 39
#define FCW14 36
#define FCW15 37
#define FCW16 34
#define FCW17 35
#define FCW18 32
#define FCW19 33
#define VLD   54
#define D_11  2
#define D_10  3
#define D_09  4
#define D_08  5
#define D_07  6
#define D_06  7 
#define D_05  8
#define D_04  9
#define D_03  10
#define D_02  11
#define D_01  12
#define D_00  13


//--------------------------------------------------------------------
void establishContact()
{
  while (Serial.available() <= 0)
  {
    Serial.print('A');  // send a capital A
    delay(300);
    if (Serial.read()==(int)'A')
      break;
  }
}
//---------------------------------------------------------------------
void setup()
{
  // start serial port at 9600 bps:
  Serial.begin(115200);
  while (!Serial)
  {
    ;  // wait for serial port to connect. Needed for native USB port only
  }
  establishContact();  // send a byte to establish contact until receiver responds

  // Set all Arduino's digital pins as INPUT mode
  //for (uint32_t dPins = 22; dPins < 54; dPins++)
  //  pinMode( dPins, INPUT);

  // Set Arduino's digital pins to output mode
  //    for DUT's input ports
  pinMode(CLK  ,OUTPUT);
  pinMode(EN   ,OUTPUT);
  pinMode(MODE ,OUTPUT);
  pinMode(SELXY,OUTPUT);
  pinMode(FCW00,OUTPUT);
  pinMode(FCW01,OUTPUT);
  pinMode(FCW02,OUTPUT);
  pinMode(FCW03,OUTPUT);
  pinMode(FCW04,OUTPUT);
  pinMode(FCW05,OUTPUT);
  pinMode(FCW06,OUTPUT);
  pinMode(FCW07,OUTPUT);
  pinMode(FCW08,OUTPUT);
  pinMode(FCW09,OUTPUT);
  pinMode(FCW10,OUTPUT);
  pinMode(FCW11,OUTPUT);
  pinMode(FCW12,OUTPUT);
  pinMode(FCW13,OUTPUT);
  pinMode(FCW14,OUTPUT);
  pinMode(FCW15,OUTPUT);
  pinMode(FCW16,OUTPUT);
  pinMode(FCW17,OUTPUT);
  pinMode(FCW18,OUTPUT);
  pinMode(FCW19,OUTPUT);
  pinMode(VLD,INPUT);
  pinMode(D_00,INPUT);
  pinMode(D_01,INPUT);
  pinMode(D_02,INPUT);
  pinMode(D_03,INPUT);
  pinMode(D_04,INPUT);
  pinMode(D_05,INPUT);
  pinMode(D_06,INPUT);
  pinMode(D_07,INPUT);
  pinMode(D_08,INPUT);
  pinMode(D_09,INPUT);
  pinMode(D_10,INPUT);
  pinMode(D_11,INPUT);

  // Preset for output pins
  digitalWrite(CLK,LOW);
  digitalWrite(EN,LOW);
  digitalWrite(MODE,HIGH);
  digitalWrite(SELXY,HIGH);
  digitalWrite(FCW00,LOW);
  digitalWrite(FCW01,LOW);
  digitalWrite(FCW02,LOW);
  digitalWrite(FCW03,LOW);
  digitalWrite(FCW04,LOW);
  digitalWrite(FCW05,LOW);
  digitalWrite(FCW06,LOW);
  digitalWrite(FCW07,LOW);
  digitalWrite(FCW08,LOW);
  digitalWrite(FCW09,LOW);
  digitalWrite(FCW10,LOW);
  digitalWrite(FCW11,LOW);
  digitalWrite(FCW12,LOW);
  digitalWrite(FCW13,LOW);
  digitalWrite(FCW14,LOW);
  digitalWrite(FCW15,LOW);
  digitalWrite(FCW16,LOW);
  digitalWrite(FCW17,LOW);
  digitalWrite(FCW18,LOW);
  digitalWrite(FCW19,LOW);

  // Monitoring ......
  //pinMode(LED_BUILTIN, OUTPUT);
  //digitalWrite(LED_BUILTIN, HIGH);
}
//---------------------------------------------------------------------
#define N_RX  3
uint8_t rxBuf[N_RX];
// [0] : | clk | En  | Mod | Sel |F[19]|F[18]|F[17]|F[16]|
// [1] : |F[15]|F[14]|F[13]|F[12]|F[11]|F[10]|F[ 9]|F[ 8]|
// [2] : |F[ 7]|F[ 6]|F[ 5]|F[ 4]|F[ 3]|F[ 2]|F[ 1]|F[ 0]|
void RxPacket()
{
  int rxByte;

  while(true)
  {
    // Resceive test vector from SC testbench
    if (Serial.available() >= N_RX)
    {
      for(int i=0; i<N_RX; i++)
      {
        rxByte = Serial.read();
        rxBuf[i] = (uint8_t)rxByte;
      }
      // Apply received test vector to DUT's input ports

      // Set IO firstly -----------------------------
      digitalWrite(FCW00,	(rxBuf[2]&0x01)? HIGH:LOW);
      digitalWrite(FCW01, (rxBuf[2]&0x02)? HIGH:LOW);
      digitalWrite(FCW02, (rxBuf[2]&0x04)? HIGH:LOW);
      digitalWrite(FCW03, (rxBuf[2]&0x08)? HIGH:LOW);
      digitalWrite(FCW04, (rxBuf[2]&0x10)? HIGH:LOW);
      digitalWrite(FCW05, (rxBuf[2]&0x20)? HIGH:LOW);
      digitalWrite(FCW06, (rxBuf[2]&0x40)? HIGH:LOW);
      digitalWrite(FCW07, (rxBuf[2]&0x80)? HIGH:LOW);
      //---------------------------------------------
	    digitalWrite(FCW08, (rxBuf[1]&0x01)? HIGH:LOW);
      digitalWrite(FCW09, (rxBuf[1]&0x02)? HIGH:LOW);
      digitalWrite(FCW10, (rxBuf[1]&0x04)? HIGH:LOW);
      digitalWrite(FCW11, (rxBuf[1]&0x08)? HIGH:LOW);
      digitalWrite(FCW12, (rxBuf[1]&0x10)? HIGH:LOW);
      digitalWrite(FCW13, (rxBuf[1]&0x20)? HIGH:LOW);
      digitalWrite(FCW14, (rxBuf[1]&0x40)? HIGH:LOW);
      digitalWrite(FCW15, (rxBuf[1]&0x80)? HIGH:LOW);
      //---------------------------------------------
	    digitalWrite(FCW16, (rxBuf[0]&0x01)? HIGH:LOW);
      digitalWrite(FCW17, (rxBuf[0]&0x02)? HIGH:LOW);
      digitalWrite(FCW18, (rxBuf[0]&0x04)? HIGH:LOW);
      digitalWrite(FCW19, (rxBuf[0]&0x08)? HIGH:LOW);
	    digitalWrite(SELXY, (rxBuf[0]&0x10)? HIGH:LOW);
      digitalWrite(MODE , (rxBuf[0]&0x20)? HIGH:LOW);
      digitalWrite(EN   , (rxBuf[0]&0x40)? HIGH:LOW);
      //---------------------------------------------
      // Then Clocking ------------------------------
      //delay(100);
      digitalWrite(CLK  ,	(rxBuf[0]&0x80)? HIGH:LOW);
      //---------------------------------------------

      return;
    }
  }
}
//---------------------------------------------------------------------
#define N_TX  2
uint8_t txBuf[N_TX];
// rxPacket[-] | (7) | (6) | (5) | (4) | (3) | (2) | (1) | (0) |
// DATA    [0] | Vld | --- | --- | --- |D[11]|D[10]|D[ 9]|D[ 8]|
//         [1] |D[ 7]|D[ 6]|D[ 5]|D[ 4]|D[ 3]|D[ 2]|D[ 1]|D[ 0]|
void TxPacket()
{
  int txByte;

  while(1)
  {
    // Capture DUT's output ports
    txBuf[0] = digitalRead(VLD)<< 7 |
				       //digitalRead(ISNEG)<< 6 |
				       //digitalRead(ISNEG)<< 5 |
				       //digitalRead(ISNEG)<< 4 |
				       digitalRead(D_11)<< 3 |
				       digitalRead(D_10)<< 2 |
				       digitalRead(D_09)<< 1 |
				       digitalRead(D_08)<< 0 ;
    
    txBuf[1] = digitalRead(D_07)<< 7 |
				       digitalRead(D_06)<< 6 |
				       digitalRead(D_05)<< 5 |
				       digitalRead(D_04)<< 4 |
				       digitalRead(D_03)<< 3 |
				       digitalRead(D_02)<< 2 |
				       digitalRead(D_01)<< 1 |
				       digitalRead(D_00)<< 0 ;


    // Send ports' captured value back to SC testbench
    if (Serial.availableForWrite() >= N_TX)
    {
      for(int i=0; i<N_TX; i++)
      {
        txByte = (int)txBuf[i];
        Serial.write(txByte);
      }

      return;
    }
  }
}
//----------------------------------------------------------------
void loop()
{
  RxPacket();
  TxPacket();
}
